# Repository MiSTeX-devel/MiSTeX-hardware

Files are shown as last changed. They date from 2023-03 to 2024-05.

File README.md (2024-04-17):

# MiSTeX-hardware

## Current
### MiSTeX baseboard for QMTech form factor FPGA boards
The QMTech-MiSTeX
baseboard is the current recommended platform. It can be used with Raspberry Pi Zero
form factor SBCs and QMTech form factor core boards.
Status: The `rev2` revision has been manufactured and tested working.

QMTech-MiSTeX Baseboard

### Using the Raspberry Pi Zero with MiSTeX, with a generic FPGA board
To connect the Raspberry Pi Zero to the FPGA board of your choice,
the pin mappings can be found in two places:
1. On the FPGA board side the pin mappings are defined in the board support file in MiSTeX-boards:
   FPGA pin mapping
2. On the Raspberry Pi Zero side, the pin mappings of the GPIO control signals are defined in Main_MiSTeX in fpga_io.cpp:
   RPi Zero pin mapping
   
   And the SPI bus is the SPI0 on the Raspberry Pi header:
   RPi SPI pins

## Obsolete
### MiSTeX Pmod
Status: Manufactured, waiting for arrival. Obsolete, Sipeed Lich





### MiSTeX cape for the Terasic DECA board
Status: Manufactured and tested working.





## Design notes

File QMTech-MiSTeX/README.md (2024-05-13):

# **MiSTeX Board**

### Connectors and main headers

- Headers for QMTech 128 pins FPGA format (2x 2x32)
- MiSTer SDRAM module header (Terasic 2x20)
- RPi header (Orange Pi 2W) (2x20)
- SNAC user port for gamepads / mt32pi (USB3)
- VGA video out (DB15)
- HDMI video out
- Analog audio out (delta sigma) (jack 3.5) 
- SPDID audio out (Toslink)
- Secondary uSD Card
- PMOD J11 header (GPIO / I2S / Delta-sigma)
- USB C for RP2040 programming
- USB C power supply

### Power Supply

It is recommended to use the USB power port since it uses a voltage filter. This port supply power to FPGA and Orange Pi as well.

The Jumper on the power port is for an external power switch mounted in a case for example. 

<u>J18 needs to be shorted with a jumper if no switch is placed</u>.



You can of course also power the board from the core board barrel jack.

### FPGA programming

Connect an USB-C from RP2040 port to the USB HUB you are using

Connect Dupont wires from FPGA JTAG to JTAG header on MiSTeX board

### Switches / Jumpers / small headers / Leds

J9 RC2040 Boot jumper. Short to reprogram RC2040 firmware

J10 SCART VGA pin 9 jumper. Short to use a VGA to SCART cable

J18 Power switch (or either place a jumper if no switch is added)

IO6 Jumper - By default shorted 2-3 for most gamepads. Some accessories require additional 3V3 power supply, in that case put jumper in position 1-2 next to +3V3 text.

SW1 Button User (RPi/Orange Pi)

SW2 Button OSD  (RPi/Orange Pi)

SW3 Button Reset  (RPi/Orange Pi)

SW4 Button Menu  (RPi/Orange Pi)

The side switches SW5, SW6 are currently unused and have been erroneously momentary in rev1, but should actually be latching which has been fixed in rev2

- SW5 (FPGA) will be used to switch the Pmod signals from I2S to general purpose use

- SW6 (RPi/Orange Pi)  is intended to switch the SNAC port from SNAC to mt32pi mode

The DIP switches are currently unused too  (RPi/Orange Pi).

User / HDD / Power Leds

DBG J7 Debug UART (RC2040)

SWD J12 Header (RC2040)

JTAG J6 Header   (RC2040)

ADC J14 Header (3 ADC + 1 GPIO)  (RC2040)

### SD image (placed at Orange Pi SD slot)

```sh
$ wget -c http://www.hans-baier.de/static/mistex-orangepizero2w.img.xz
$ md5sum mistex-orangepizero2w.img.xz
30ea6324ea5340d76d8ffbd25d986887  mistex-orangepizero2w.img.xz
```

The boot image needs the menu core at /media/fat/menu.bit
or menu.rbf for Altera boards
The sdcard image above is preconfigured for the Artix 100t QmTech with pre built cores
But A200T and K325T cores are included too
You only need to copy the right one to menu.bit

### RP2040 firmware

You need to bridge the boot jumper J9 and plug the RC2040 USB port into a PC to flash this firmware: https://github.com/MiSTeX-devel/pico-dirtyJtag/releases/tag/v0.0.1
The core FPGA board needs to be present there because it powers the 2040 except you power the 3.3v rails from another source.

Connect power supply either to FPGA barrel or USB-C power port.

Copy the uf2 file into the mass storage device that appears on PC. When the file disappears it means it is flashing the firmware. Wait a bit and disconnect USB-C and remove jumper.

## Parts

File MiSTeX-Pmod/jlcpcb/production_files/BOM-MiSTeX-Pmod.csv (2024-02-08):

Comment | Designator | Footprint | LCSC
100nF | C1 | C_0402_1005Metric | C1525
Connector_USB_C_Receptacle_USB2.0 | J5 | USB-C_SMD-TYPE-C-31-M-12 | C165948
LXES15AAA1-133 | D2,D3,D4,D5,D6,D7,D8 | D0402-BI | C191267
Schottky | D1 | D_SMA | C22452
100R | R3 | R_0402_1005Metric | C25076
22R | R1,R2 | R_0402_1005Metric | C25092
47R | R5,R6,R7,R8 | R_0402_1005Metric | C25118
TS-1187A-B-A-B | SW1 | SW-SMD_4P-L5.1-W5.1-P3.70-LS6.5-TL-2 | C318884
NASB0-S6701-TS50 | CN1,CN2 | CONN-SMD_67P-P0.50-V_NASB0-S6701-TS50 | C367024
USB_A | J2 | USB-A-SMD_GT-USB-2004-CWG1A | C5117890
JK-NSMD050-30V | F1 | F1206 | C720075
TestPoint | TP1 | TestPoint_Pad_D2.0mm
Pmod | J1 | Pmod 2x6
TestPoint | TP5 | TestPoint_Pad_D2.0mm
Conn_01x03_Male | J3 | PinHeader_1x03_P2.54mm_Vertical
Pmod | J4 | Pmod 2x6
MountingHole_Pad | H1 | MountingHole_2.2mm_M2_ISO7380_Pad_TopBottom
Sipeed Lichee | H2 | Sipeed Lichee

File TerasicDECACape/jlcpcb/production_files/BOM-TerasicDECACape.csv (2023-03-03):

Comment | Designator | Footprint | LCSC
USB_A | J2 | USB-A-SMD_USB-302S | C112455
100nF | C1 | C_0402_1005Metric | C1525
LXES15AAA1-133 | D10,D11,D12,D13,D14,D15,D16,D2,D3,D4,D5,D6,D7,D8,D9 | D0402-BI | C191267
Schottky | D1 | D_SMA | C22452
100R | R3 | R_0402_1005Metric | C25076
22R | R1,R2 | R_0402_1005Metric | C25092
47R | R5,R6,R7,R8,R9 | R_0402_1005Metric | C25118
10k | R4 | R_0402_1005Metric | C25744
TS-1187A-B-A-B | SW1,SW2 | SW-SMD_4P-L5.1-W5.1-P3.70-LS6.5-TL-2 | C318884
NASB0-S6701-TS50 | CN1,CN2 | CONN-SMD_67P-P0.50-V_NASB0-S6701-TS50 | C367024
JK-NSMD050-30V | F1 | F1206 | C720075
BeagleBone_Black_Header | P8 | Socket_BeagleBone_Black
BeagleBone_Black_Header | P9 | Socket_BeagleBone_Black
MiSTer SDRAM Module | J1 | PinHeader_2x20_P2.54mm_Vertical
Conn_01x03_Male | J3 | PinHeader_1x03_P2.54mm_Vertical
Conn_02x06_Odd_Even | J4 | PinSocket_2x06_P2.54mm_Vertical
MountingHole_Pad | H1 | MountingHole_2.2mm_M2_ISO7380_Pad_TopBottom
Sipeed Lichee | M1 | Sipeed Lichee
TestPoint | TP1 | TestPoint_Pad_D2.0mm
TestPoint | TP6 | TestPoint_Pad_D1.0mm
TestPoint | TP4 | TestPoint_Pad_D2.0mm
TestPoint | TP2 | TestPoint_Pad_D1.0mm
TestPoint | TP5 | TestPoint_Pad_D1.0mm
Conn_02x02_Odd_Even | J5 | PinHeader_2x02_P2.54mm_Vertical
TestPoint | TP3 | TestPoint_Pad_D1.0mm

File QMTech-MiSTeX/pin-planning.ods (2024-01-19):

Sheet: Pinstats
Total Pins |  | 108 | Remaining | 22
HDMI
 | Video | 24
 | Sync | 4
 | Audio | 1
 | I2C | 2
 | INT | 1
SDRAM |  | 36
HPS | SPI | 5
 | GPIO | 4
 | UART | 2
USER IO |  | 7

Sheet: Pinout
A100T | K325T
R55S
R56S
R50S | R52S
R49S | R51S
R46
R45
R38 | R36
R37 | R35
R31S
R32S
R24
R23
R22
R21
R20S | R18
R19S | R17
 | R14
 | R13
L17 | L15
L18 | L16
L35S | L33
L36S | L34
 | L25S
 | L26S
 | L29S
L41 | L30S
L42 | L57S
L47 | L58S
L48 | L53S
 | L54S

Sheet: Diffpairs
 |  |  | 100R
 | mm | mil | mil | mm
Defaultwidth | 0.25 | 9.84251968503937 | 6.05 | 0.15367
Default gap | 0.127 | 5 | 5 | 0.127
 |  |  | 8.08 | 0.205232
 |  |  | 8 | 0.2032
 |  |  |  | 0
 |  |  |  | 0

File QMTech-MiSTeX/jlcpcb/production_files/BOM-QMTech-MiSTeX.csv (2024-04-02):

Comment | Designator | Footprint | LCSC
10uH | L1,L2,L3,L4,L5 | L0805 | C1046
UWX1C101MCL1GB | C47 | CAP-SMD_BD6.3-L6.6-W6.6-FD | C111600
1k | R11,R31,R36,R37,R53,R54,R55,R56,R59,R60,R61,R63,R65,R70,R9 | R_0402_1005Metric | C11702
W25Q128JVS | U1 | SOIC-8_5.23x5.23mm_P1.27mm | C131025
100n | C43,C52 | C_0603_1608Metric | C14663
100uF | C41,C42,C46 | C1206 | C15008
10nF | C37,C38,C39,C40 | C_0402_1005Metric | C15195
100nF | C1,C11,C12,C13,C14,C15,C16,C23,C24,C25,C26,C27,C28,C29,C30,C31,C32,C33,C34,C35,C4,C44,C5,C55,C6,C9 | C_0402_1005Metric | C1525
30pF | C2,C3 | C_0402_1005Metric | C1570
1u | C10,C17,C7 | C_0603_1608Metric | C15849
10u | C53 | C_0805_2012Metric | C15850
USB_C_Receptacle_USB2.0 | J13,J3 | USB_C_Receptacle_XKB_U262-16XN-4BVC11 | C165948
10n | C51 | C_0805_2012Metric | C1710
0R | R14,R17,R18,R19,R20 | R_0402_1005Metric | C17168
0R | R1,R3 | R_0805_2012Metric | C17477
10u | C18,C19,C20,C21,C22,C36,C45,C54,C8 | C_0603_1608Metric | C19702
1k | RN1,RN10,RN11,RN12,RN13,RN14,RN15,RN2,RN3,RN4,RN5,RN6,RN7,RN8,RN9 | RES-ARRAY-SMD_0603-8P-L3.2-W1.6-BL | C20197
RP2040 | U2 | LQFN-56_L7.0-W7.0-P0.4-EP | C2040
0R | R52,R74 | R_0603_1608Metric | C21189
16k | R28,R29,R30 | R_0603_1608Metric | C22818
blue | D7 | LED_0805_2012Metric | C2293
1M | R22,R25,R35,R39,R6 | R_0603_1608Metric | C22935
5k1 | R7,R71,R72,R8 | R_0603_1608Metric | C23186
560R | R32,R33,R34,R47,R48,R49,R50,R73 | R_0603_1608Metric | C23204
100R | R26,R27,R40,R41,R42,R43,R44,R45,R46 | R_0402_1005Metric | C25076
51R | R5 | R_0402_1005Metric | C25125
27R | R12,R13 | R_0603_1608Metric | C25190
10k | R21 | R_0402_1005Metric | C25744
4.7k | R38,R57,R58,R62,R64,R66,R67,R68,R69 | R_0402_1005Metric | C25900
ZGY133/T10(PLT) | U5 | COMM-TH_ZGY133-T10-PLT | C277782
PJ-325C5-BL | CN1 | TH_PJ-325C5-B | C2884946
TPD4E05U06DQAR_C2972498 | D1,D10,D12,D13,D14,D2,D3,D4,D5,D9 | DFN2510-10_L2.5-W1.0-P0.50-BL | C2972498
U-A-39WD-W-1 | USB1 | USB-A-SMD_U-A-39WD-W-1 | C3020886
KH-HDR15P-F3.08 | VGA1 | DSUB-TH_KH-HDR15P-F3.08-VGA | C3038673
6A | FB1 | L_1206_3216Metric | C304333
TS-1187A-B-A-B | SW1,SW2,SW3,SW4 | SW-SMD_4P-L5.1-W5.1-P3.70-LS6.5-TL-2 | C318884
white | D6 | LED_0805_2012Metric | C34499
DSHP04TSGER | SW7 | SW-SMD_8P-L6.7-W5.4-P1.27-LS8.4 | C40736
ADV7513BSWZ | U4 | LQFP-64_L10.0-W10.0-P0.50-LS12.0-BL-EP5.3 | C408901
2k | R16,R23,R24 | R_0402_1005Metric | C4109
887R | R15 | R0402 | C474137
100nF | C48,C49,C50 | C_0805_2012Metric | C49678
TPS76318 | U3 | SOT-23-5 | C7099
D_LED_0603_Yellow | D15 | LED_0603_1608Metric | C72038
HDMI-001S | HDMI1 | HDMI-SMD_HDMI-001S | C720616
TF-CARD H1.8 | TF1 | TF-SMD_TF-CARD-H1.8 | C7529389
XKB5858-W-F-75 | SW5,SW6 | SW-SMD_XKB5858-W-F-75 | C780036
P6SMB6.8CA-C78395 | D11 | SMB_L4.6-W3.6-LS5.3-BI | C78395
red | D8 | LED_0805_2012Metric | C84256
U.FL-R-SMT-1(80) | CN2,CN3,CN4,CN5,CN6,CN7,CN8 | RF-SMD_FRF05002-JSS103M | C88374
X322512MSB4SI | X1 | OSC-SMD_4P-L3.2-W2.5-BL | C9002

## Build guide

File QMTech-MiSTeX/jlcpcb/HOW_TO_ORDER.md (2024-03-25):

# How to order
These are the settings I used. You probably
can use cheaper options where I mentioned it,
but I have not tried those, so do that at your own risk.

1. Go to https://cart.jlcpcb.com/quote
2. Click `Add Gerber File`
3. Choose `production_files/GERBER-QMTech-MiSTeX.zip`
4. Material type: FR4-TG155 (optional, costs marginally more, less warping)
5. Surface finish: ENIG (optional, lead free HASL also might work)
6. Impedance control: Yes, JLC04161H-7628, press `Confirm`
7. Leave the rest at default (optionally use `Confirm production file`), activate the Assembly switch
8. Confirm parts placement: Yes (important, the import of those is not perfect and has to be corrected by an employee,
                                 so you need to check if the placements are good)
9. PCBA Qty: I recommend 5, because it only costs about 20% more and does not waste PCBs, but use 2 at your own discretion.
10. Make sure `Assemble top side`  is chosen
11. Click `Confirm`
12. A PCB viewer will come up, press 'Next'
13. Select `production_files/BOM-QMTech-MiSTeX.csv`  as BOM file and `production_files/CPL-QMTech-MiSTeX.csv` as CPL file
14. Press `Process BOM & CPL`
15. A list of parts should come up. Make sure they are all available and press `Next`
16. A window with the component placements comes up. Note that some connectors (USB-C, VGA and TOSLINK)
    can be out of place. Just leave them. A JLCPCB engineer will fix those, and then ask you for review
    after the order has been submitted (Confirm parts placement).
17. Press 'Save to Cart'
18. You can then Check out our cart and order the PCBs

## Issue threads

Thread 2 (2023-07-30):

Addressing MiSTer shortcomings with MiSTeX in the future?

jan-kleks, 2023-07-30:
Hello,

This is a great project, and I am quite sure that I am not the only person closely watching it. MiSTer is awesome, but it has some shortcomings:

- you have to take additional actions to make sure your game is saved: https://mister-devel.github.io/MkDocs_MiSTer/basics/saves/ This is the case even with Autosave turned on: https://www.youtube.com/watch?v=V0s-lkA9MD8 -- the devices from Analogue do not have this problem.

- only one SNAC port

- USB input could be more in sync with the cores. See: https://www.atari-forum.com/viewtopic.php?f=117&t=38741

- maybe the framework could be adapted to make it easier to add save states to cores. At least those flashcart-like save states, see the discussion from Discord about them:

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

- it would be nice if a MiSTeX FPGA board could have more than one "retro use". Have you seen this video about creating a Game-Genie for Atari 2600 with a DE0-Nano FPGA board? -- https://www.youtube.com/watch?v=lXTxKD8-ghg

It might be worth looking into turning a MiSTeX board in a similar way into a "multi-flashcart" for developers. With wide-range support of mappers/expansion chips in MiSTer FPGA, I guess it could have been used together with various gaming retro hardware.

One could utilize it, for instance, for homebrew development (see how this scene is evolving! -- https://www.youtube.com/watch?v=1AGMEZvU14g) or creating test ROMs to compare FPGA implementations with original devices without buying "tons" of flashcarts.

Though obviously not as portable and nice-looking as standard flashcarts -- for development it should be just fine.

Using MiSTeX as a video scaler for original consoles/computers could be another interesting idea…

Keep up the great work!

hansfbaier, 2024-04-17:
Yes, you could use it as a game genie.
The SDRAM port uses the same layout as the Altera DE0 boards, and you
can also plugin in standard MiSTer SDRAM modules.
Of course, you can plug in anything else there.
You just have to be careful what core you load.
The baseboard is actually quite general purpose,
you can also use it as a dev board for educational purposes.

hansfbaier, 2024-04-17:
Why shouldn't you be able to use it for homebrew development?
What features would that need?

jan-kleks, 2024-04-17:
> Why shouldn't you be able to use it for homebrew development? What features would that need?

I mean, it would have been nice to be able to use it like a universal flashcart with a set of additional exchangeable hardware "cartridge-like plugs" that you would put into a given console. In general, it would have been cool if MiSTeX was even more than a universal console/computer.

hansfbaier, 2024-04-18:
Of course you can use it like that with the SDRAM port and custom gateware.
No problems with that, but you really would not need the baseboard for that.
You could also use the core board for that.
In any case you would need a suitable adapter for the cartriges.

tomaszb-dev, 2024-05-21:
Hello,
Will the board be appropriate for the project.
QMTECH Xilinx FPGA Kintex7 Kintex-7 XC7K325T DDR3

hansfbaier, 2024-05-23:
@tomaszb-dev You mean this one?
https://de.aliexpress.com/item/1005003668804223.html
You can use it even now. I recently built all working core ports for it also.
I just don't recommend it for development work because you need a paid license ($3k).
Also currently it offers no material advantage over a 100T and a 200T because there are no cores that would use its strength.

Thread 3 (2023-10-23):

rpi-zero wiring diagram

siffland, 2023-10-23:
Is there an updated diagram or pinout how you are attaching the rpi-zero to the FPGA boards, preferably the qmtech boards.

Thanks,
Sean

hansfbaier, 2023-10-24:
Hi, the Pin assignments can be found in the
python build files in MiSTeX-boards:
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
You need to wire up those to the SPI0 and the four GPIO lines I configured in the MainMiSTeX binary.
I didn't have the time to do it myself, my paid work is rather demanding at the moment.
Here are the Pin assignments:
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

hansfbaier, 2023-10-25:
https://pinout.xyz/pinout/pin32_gpio12/

hansfbaier, 2023-11-07:
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

hansfbaier, 2023-11-07:
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

hansfbaier, 2023-11-07:
OK, added this information to the README, closing this issue:
https://github.com/MiSTeX-devel/MiSTeX-hardware/blob/main/README.md

Closed 2023-11-07.

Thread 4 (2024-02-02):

QMTech hardware

DFL1973, 2024-02-02:
Hello, I just saw the PCB for QMtech that you added a few days ago. Is it working already or is it just an untested concept?
Thanks for sharing, you are doing a great job!

hansfbaier, 2024-02-02:
Hi, I will find out tomorrow or on Monday, when the boards arrive at my home.

hansfbaier, 2024-04-17:
Hi it is working!
You can order rev2, and see the picture in the README, I just updated it.

Closed 2024-04-17.

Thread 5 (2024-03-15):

MiSTeX coming along

magwed, 2024-03-15:
Nice to see that this is still in development. Where is the general channel for chatting/sharing info about MiSTeX? I can't see any discussion forum here, there is no facebook group and I can't find anything in Discord. Are there anything hidden that I can get myself invited to or is this a closed project right now? I'm really interested in seeing where this can lead, what tool chains that are used, how the hardware currently are working, which hardware is used, what's next? Thanks!

no-shad, 2024-03-15:
On the patreon there was an invite to a group posted but I found it to be expired when I tried to join

hansfbaier, 2024-03-16:
@magwe @no-shad I updated the Link on Patreon: Here is the invite:
https://t.me/+kuN3TVEjBSAxMDg0

Closed 2024-03-16.

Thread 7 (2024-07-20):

MisteX hardware questions

ole00, 2024-07-20:
HI,
MisteX looks like an interesting project. Is there an update what are the current hardware components for MisteX base board? I saw that in the past you were using Allwinner D1, there are mentions of Orange Pi 2W and Raspberry Pi Zero. There also seem to be a RPi 2040 IC on the Mistex Board? You don't seem to have pictures how all these boards connect together. Also there seem to be some hardware on the Mistex Base board that looks to be optional (is it?) like HDMI, uSD card etc.

I think for the clarity of the project it would be good to document:

**1) what is the bare minimum HW components on the MisteX baseboard:**
- Is Rpi 2040 required ? If so, what purpose does it serve?
- Is uSD card required? I think MiSTer does not seem to use it much these days.
- Is HDMI required? Is the VGA functional without HDMI?
- Is the IC next to HDMI connector related to HDMI signal generation ? Can it be omitted if HDMI is not used?
- Is USB-C required for Power? If not, what voltage and amp rating Power supply can be used for powering MisteX?
- What are these SMA connectors for and do they need to be populated? Are they all required?
- What is the USB-A connector for ? Is it for SNAC? Is SNAC required?

The purpose of this doc/QA would be to find the smallest (and simplest to build) configuration of a functional
MisteX board. For example I don't need HDMI, I'd be happy to use external power supply (Without USB-C) and I don't
need SNAC if the Rpi Zero can be used for input.

**2) Which SBC is required** (Rpi Zero, Orange Pi ?), which one is supported by the Buildroot image? What is your favourite one that will be (likely) supported going forward?

**3) Which FPGA modules are supported** and could you provide a link where to buy them? If there are multiple, which one  is more likely be supported in the future?

Thanks.
Apology if these questions are already answered.

EDIT: I can see you have a  JLCPCB directory for production and assembly of the base board. That's a good option however it adds costs and from my experience the ICs may not always be available at LCSC, so the production my not be fully done if there is a shortage of particular chip.  I would prefer to build MisteX base board on my own - and to make it simple I'd like not to use the small pitch IC and passives (0402 are not very friendly to solder at home) - I guess that would mean redesign of the board - hence my questions above, which are related to very minimal yet functional MisteX base board.

EDIT2: Checking the Aliexpress site for MisteX compatible QMTECH FPGA module,  I found this board:
QMTECH Intel Altera CycloneV Cyclone V SoC FPGA 5CSEMA6U23 Development Board
which may be compatible with MiSTer on hardware level (and seems to have on board SDRAM, reducing the overall costs of the MiSTer system). Therefore, unless a new FPGA core needs  more FPGA resources than MiSTer can support, then building MisteX probably does not make much sense (it is still a good hobby project and and and electronic skill exercise though).

hansfbaier, 2024-07-21:
Hi, sorry for the late replay, just came back from vacation.
Here the answers:
1)
* The onboard rp2040 works as a JTAG adapter using pico-dirtyJtag, used to program the FPGA
* A uSD card is only required for the Orange Pi Zero 2W. Currently no working ported cores use the SDCARD slot on the baseboard. But the minimig may in the future.
* Yes VGA works without HDMI. It uses the same signal path than HDMI of MiSTer (not the MiSTer VGA signal path)
* Yes it is the HDMI chip used on the DE10 nano, and it may be left out if no HDMI is needed
* The backside USB-C connector is for power only and a 5W power supply may be enough
* The uFL connectors are for oscilloscope connection (debugging the board) with an integrated 1k-resistor probe. They do not need to be populated in production
* Yes it is for SNAC and it is not required if you don't use SNAC
2) We currently use the Orange Pi Zero 2W. Great price and performance. (RPi zero version one also works but is slow).
3) The supported boards are currently:
https://de.aliexpress.com/item/4000170003461.html
https://de.aliexpress.com/item/1005002960622091.html
https://de.aliexpress.com/item/1005003668804223.html
But the A100T variant is the main target at the moment, since it is enough for all ported cores, and probably will be for all other cores at the moment.
If QMTech still don't ship to germany, you can also order via taobao.com
using the item link https://world.taobao.com/item/694209022837.htm
for the A100T board.
This is the TaoBao store of QMTech: https://world.taobao.com/dianpu/61835962.htm

Yes the QMTech CycloneV board may be MiSTer compatible and won't need MiSTeX.
Not sure if it is pin compatible, but at worst you will need to recompile the game cores with different pin assignments.

hansfbaier, 2024-07-23:
By the way, if you want a ready made board, you can ask in our community channel.
There are still members with spare boards.
https://t.me/+kuN3TVEjBSAxMDg0

ole00, 2024-07-23:
Thank you for the answers. I appreciate your time answering my questions.  I like your effort of porting MiSTer to other HW platforms. I would prefer an FPGA with open source toolchain, something like this (the i9 option):
https://de.aliexpress.com/item/1005002997672924.html?spm=a2g0o.productlist.main.3.540aLRSTLRSTpn
I understand, there is not nearly as much as LUTs on ECP5 (only 44k) compared to Xilinx boards you use, so these
may not be a good option for a MiSTer port. OTOH they are slightly cheaper than the QMTECH FPGA boards.

Ready made MisteX board: I think I'll try something a bit different. The idea is to use real retro CPUs and exchangeable audio chips (via pluggable cards with real AY-3 or YM2204) on a base board. Then to have a smaller grade reprogrammable CPLDs and a FPGA to provide a glue logic and a video circuitry for the game/machine to operate correctly with the original software.  I'd probably start with a dual Z80 configuration - these were quite popular in 80s and there are some nice machines.

hansfbaier, 2024-07-24:
There is an open source toolchain
https://github.com/openXC7
And yes the Lattice part is too small.
And the system verilog and VHDL capabilities of the open source toolchains are currently the main limitation for MiSTer cores.

hansfbaier, 2024-07-24:
That is a yosys problem

ole00, 2024-07-24:
Thanks for the link to openXC7 - I was not ware such a tool exists. Did you attempt to compile MisteX cores by openXC7? If so, did it work?

> That is a yosys problem

I'm not sure I understand the context. Did you mean that yosys can be used to compile code for Altera's FPGAs, but currently unable to produce/fit Cyclon V binaries?

hansfbaier, 2024-07-24:
Yosys is the synthesis frontend for any architecture. Its system verilog and VHDL psrsers have limitations.

ole00, 2024-07-25:
I see, so that means MiSTer and MiSTEX FPGA cores can't be 'compiled' by Yosys (at this time) because of some limitations. I guess the only remedy would be to improve Yosys parser to support the limiting /missing functionality. Is there a list of what is missing / not supported by the parser, specifically for MiSTer/MisteX?

hansfbaier, 2024-07-25:
not really I think apart from the yosys issue tracker. I would just try it out, where it falls short

Closed 2024-07-21.

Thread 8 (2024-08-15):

BOM

tomaszb-dev, 2024-08-15:
Hello,
So i acquired the xillinx fpga board and ordered MisteX pcb. Maybe it's me but I cannot find any BOM for the parts.

hansfbaier, 2024-08-15:
Hello,
the complete production files including the BOM are here:
https://github.com/MiSTeX-devel/MiSTeX-hardware/tree/main/QMTech-MiSTeX/jlcpcb/production_files

They are actually complete for JLCPCB assembly, so you can have the complete board made there for comparatively
little money.

Also in the Telegram community chat there are several people who still have spare boards to sell.
I am closing this issue, please comment below if you have further questions.

hansfbaier, 2024-08-15:
No it is a 4 layer board

hansfbaier, 2024-08-15:
Please ask in the community chat,
several members have an assembled board to sell
https://t.me/+kuN3TVEjBSAxMDg0

tomaszb-dev, 2024-08-15:
By the way will you open a channel on discord

tomaszb-dev, 2024-08-15:
That will be much cheaper (40 Euro or so). Maybe I will do so. However I already ordered 5 PCBs. I will have to solder them. It will be a lot of resistors and caps :D

Closed 2024-08-15.

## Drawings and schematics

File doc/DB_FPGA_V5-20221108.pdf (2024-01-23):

RP2040

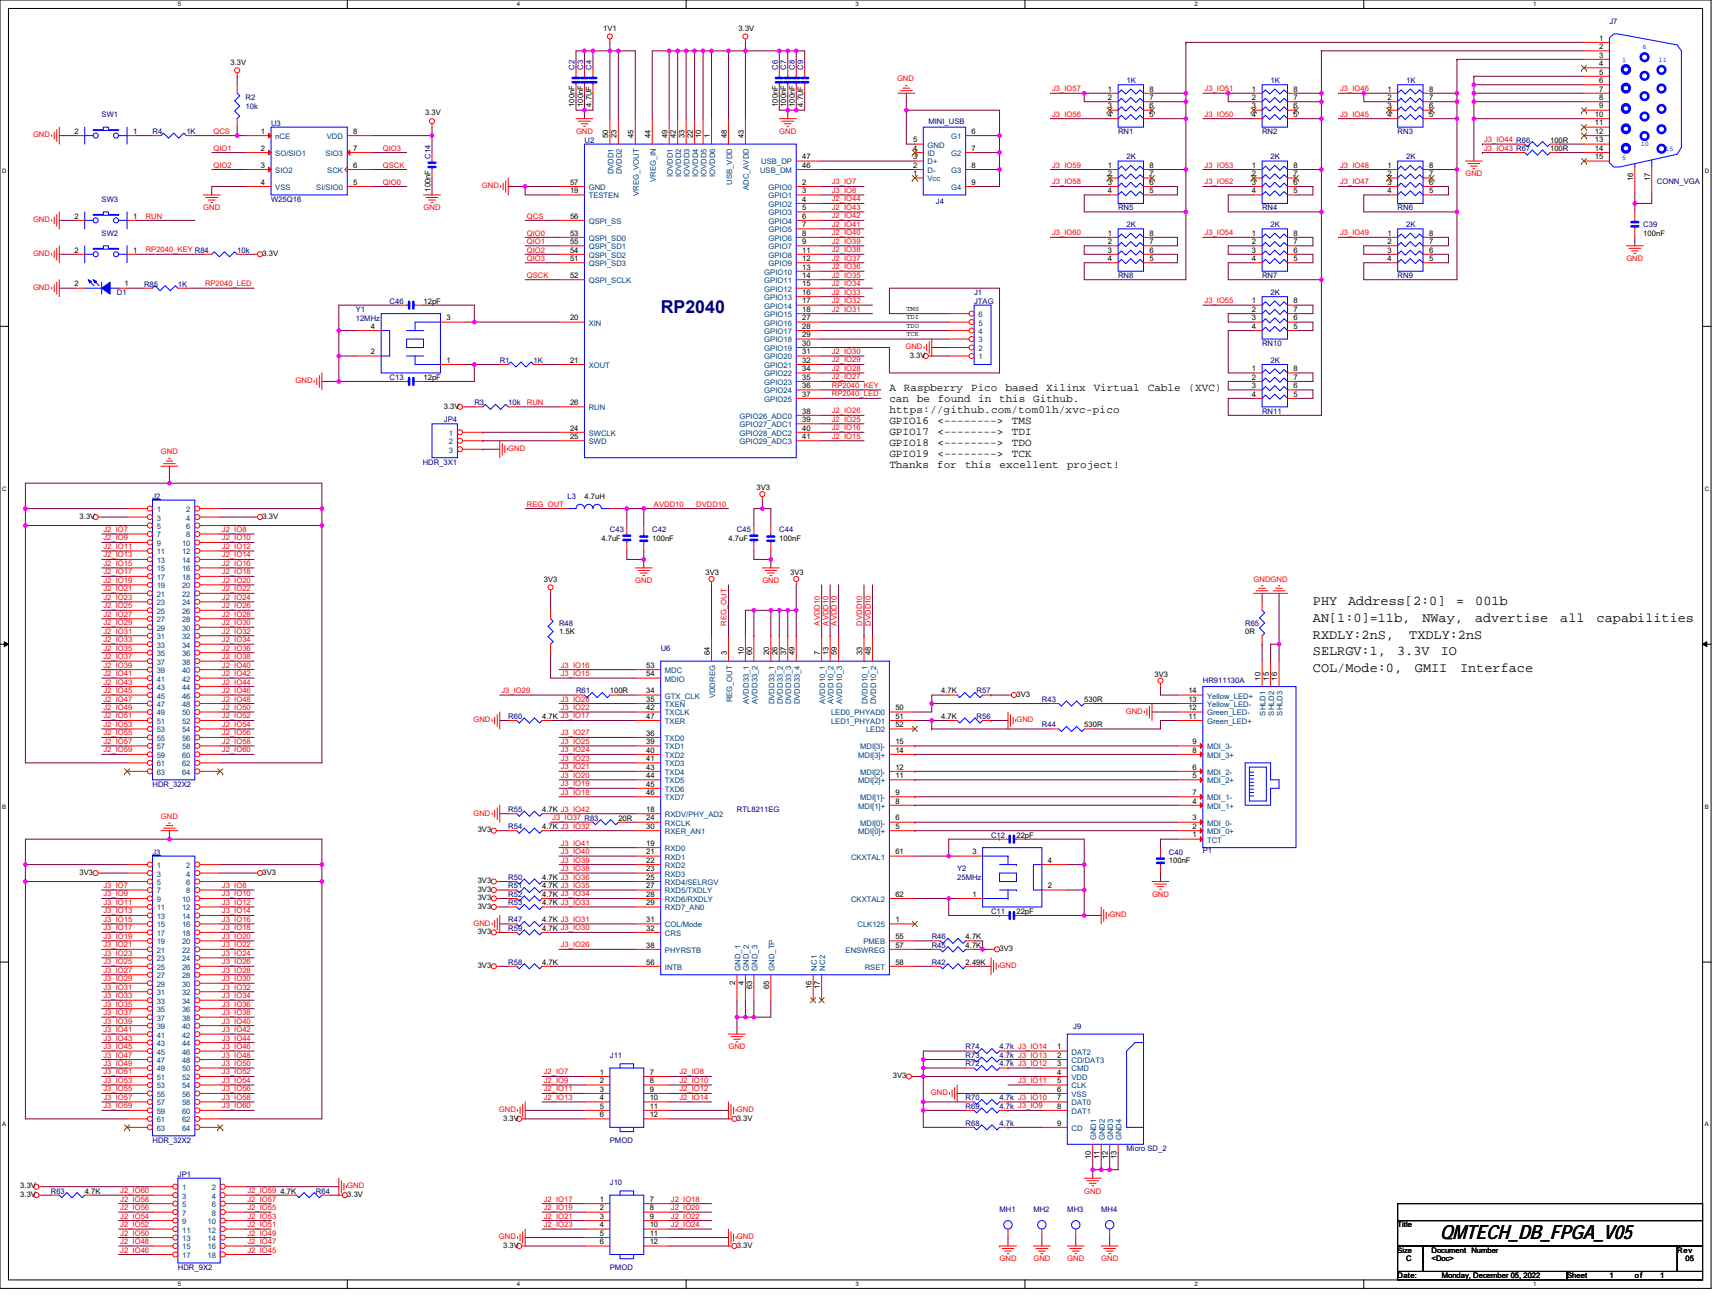
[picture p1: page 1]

A Raspberry Pico based Xilinx Virtual Cable (XVC)
can be found in this Github.
https://github.com/tom01h/xvc-pico
GPIO16 <--------> TMS
GPIO17 <--------> TDI
GPIO18 <--------> TDO
GPIO19 <--------> TCK
Thanks for this excellent project!

GND
PHY Address[2:0] = 001b
AN[1:0]=11b, NWay, advertise all capabilities
RXDLY:2nS, TXDLY:2nS
SELRGV:1, 3.3V IO
COL/Mode:0, GMII Interface

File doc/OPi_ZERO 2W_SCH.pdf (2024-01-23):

D | D

# 1.Note that the voltage of SOC GPIO must matches the

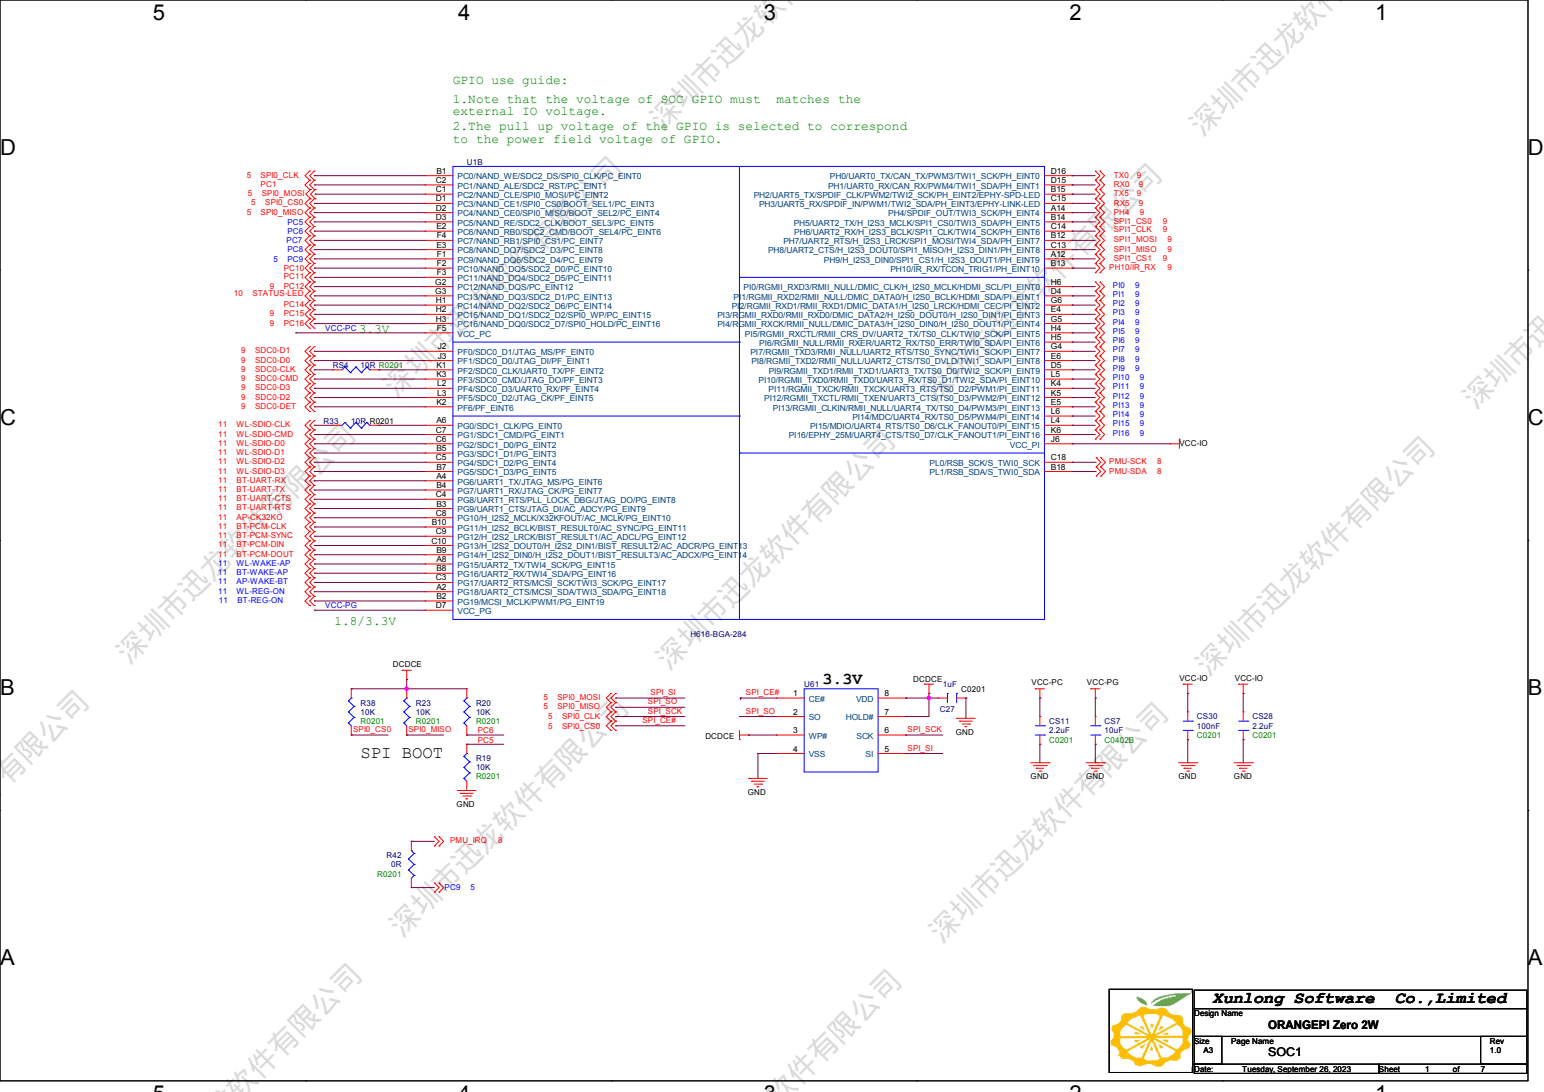
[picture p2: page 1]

深圳市迅龙软件有限公司 深圳市迅龙软件有限公司 深圳市迅龙软件有限公司 深圳市迅龙软件有限公司 深圳市迅龙软件有限公司 深圳市迅龙软件有限公司 深圳市迅龙软件有限公司 深圳市迅龙软件有限公司 深圳市迅龙软件有限公司 深圳市迅龙软件有限公司 深圳市迅龙软件有限公司 深圳市迅龙软件有限公司 深圳市迅龙软件有限公司 深圳市迅龙软件有限公司 深圳市迅龙软件有限公司

GPIO use guide:
external IO voltage.
2.The pull up voltage of the GPIO is selected to correspond
to the power field voltage of GPIO.

Xunlong Software Co.,Limited

D | D

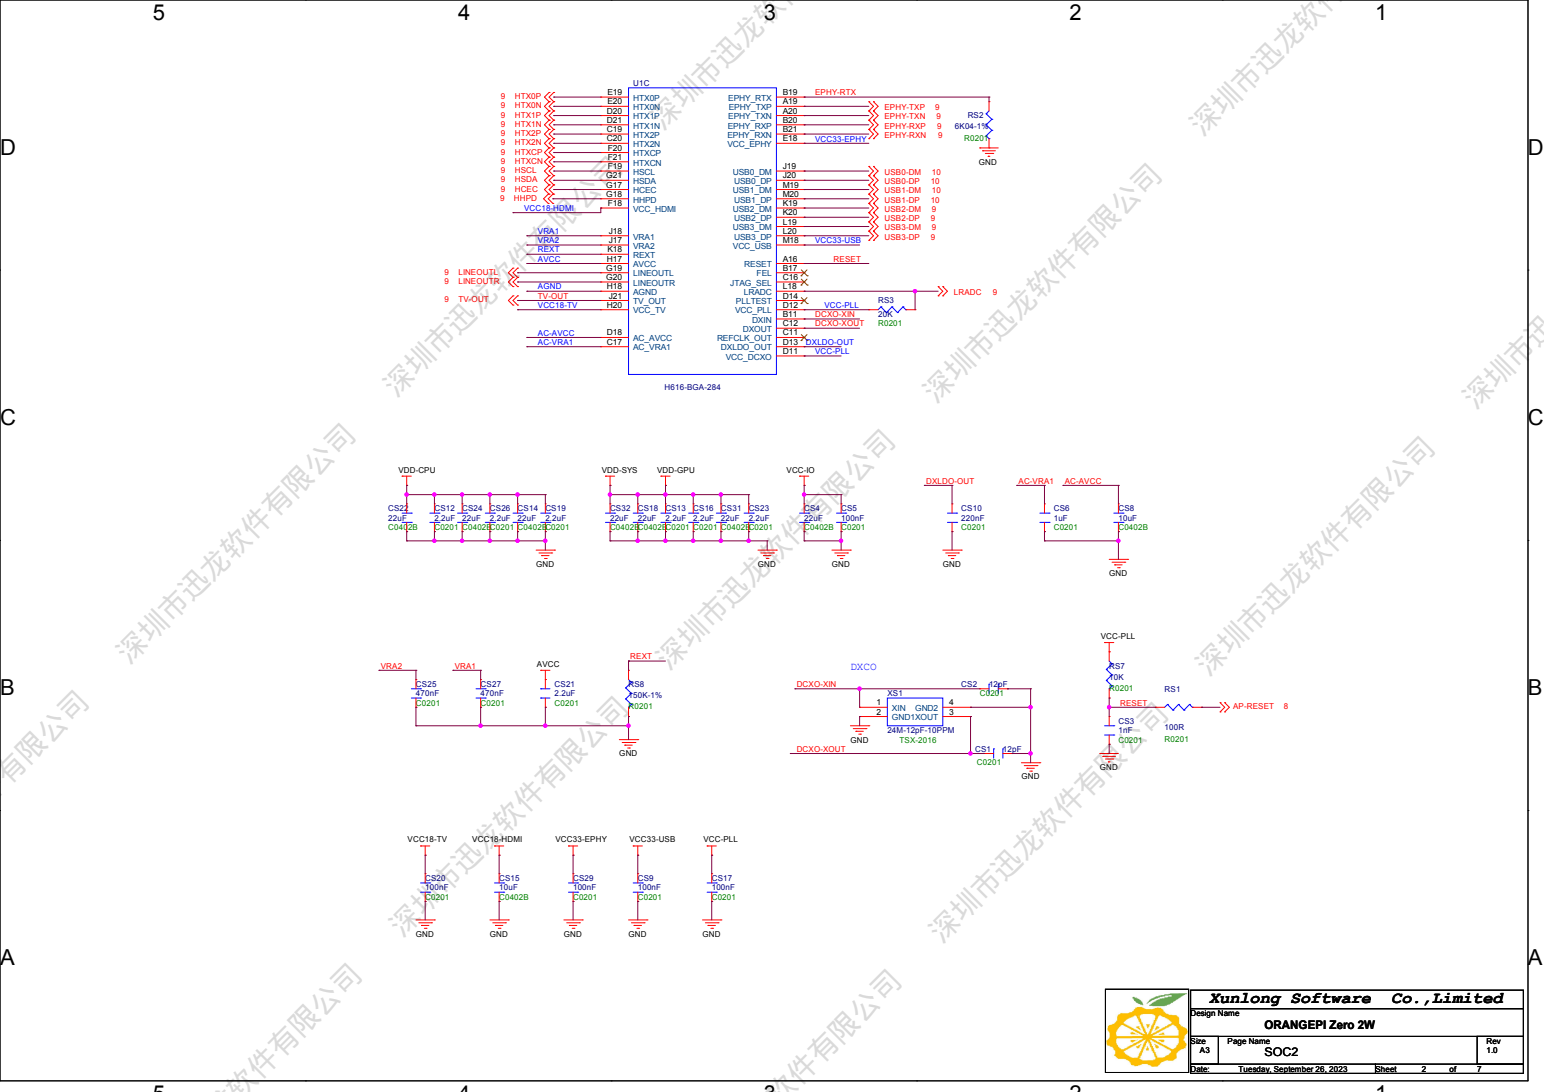
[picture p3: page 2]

深圳市迅龙软件有限公司 深圳市迅龙软件有限公司 深圳市迅龙软件有限公司 深圳市迅龙软件有限公司 深圳市迅龙软件有限公司 深圳市迅龙软件有限公司 深圳市迅龙软件有限公司 深圳市迅龙软件有限公司 深圳市迅龙软件有限公司 深圳市迅龙软件有限公司 深圳市迅龙软件有限公司 深圳市迅龙软件有限公司 深圳市迅龙软件有限公司 深圳市迅龙软件有限公司 深圳市迅龙软件有限公司

Xunlong Software Co.,Limited

D | D

# LPDDR4

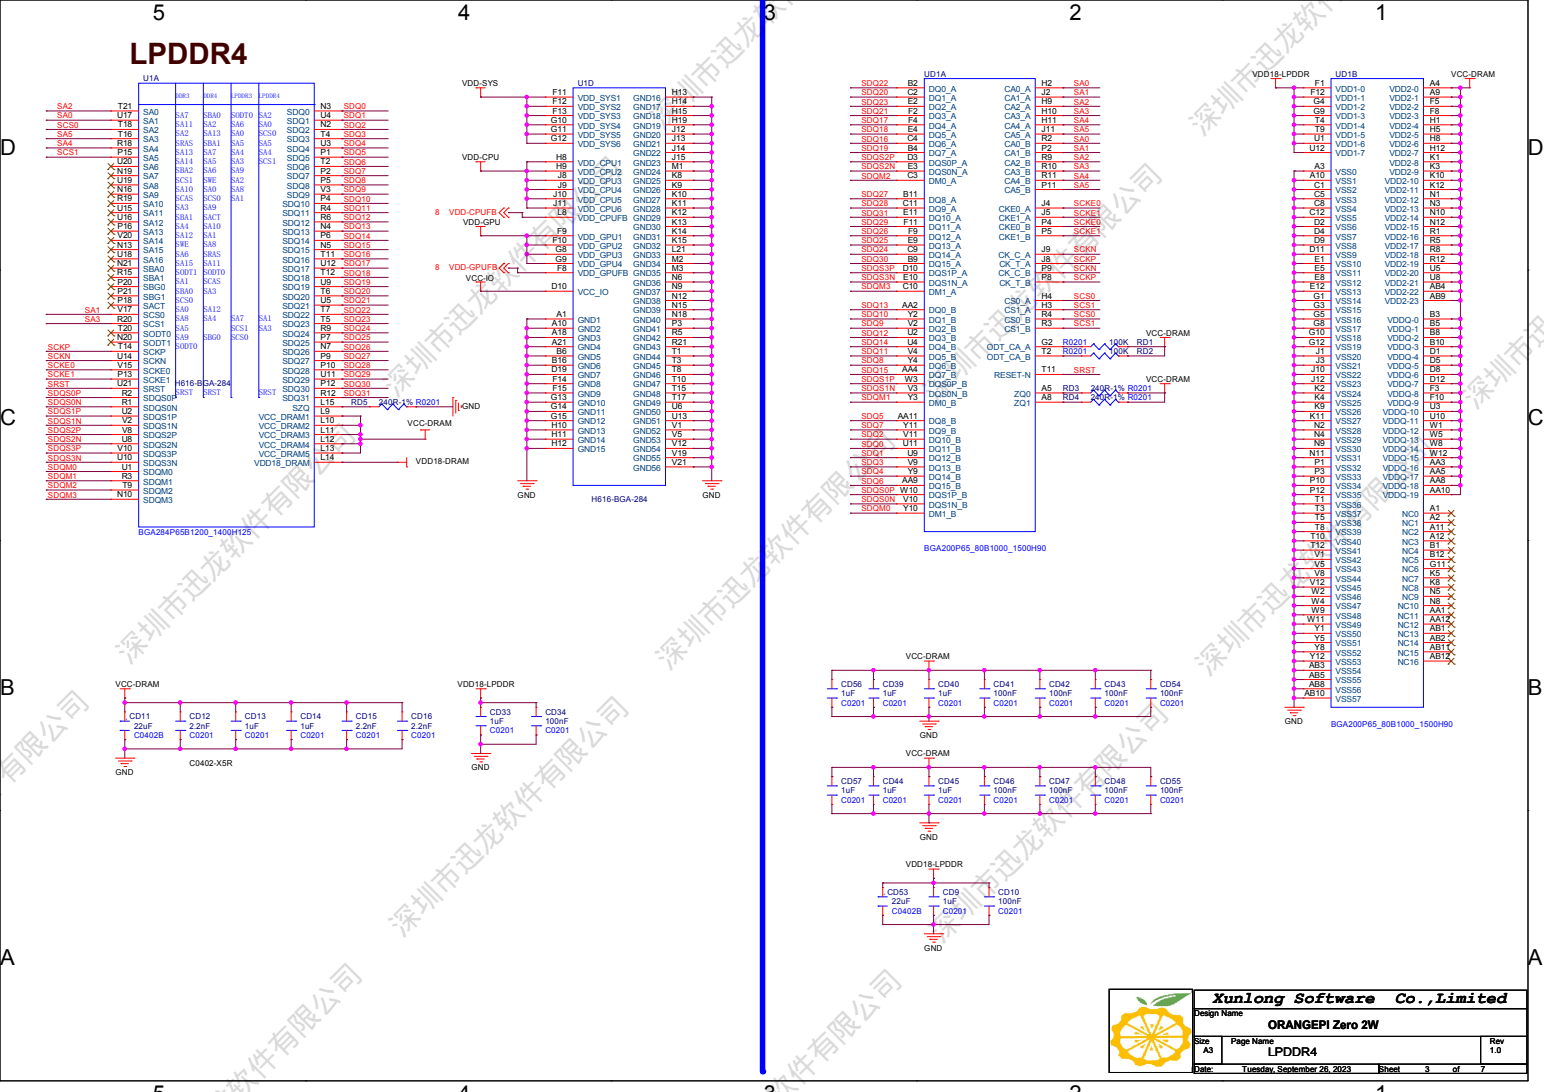
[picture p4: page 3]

深圳市迅龙软件有限公司 深圳市迅龙软件有限公司 深圳市迅龙软件有限公司 深圳市迅龙软件有限公司 深圳市迅龙软件有限公司 深圳市迅龙软件有限公司 深圳市迅龙软件有限公司 深圳市迅龙软件有限公司 深圳市迅龙软件有限公司 深圳市迅龙软件有限公司 深圳市迅龙软件有限公司 深圳市迅龙软件有限公司 深圳市迅龙软件有限公司 深圳市迅龙软件有限公司 深圳市迅龙软件有限公司

Xunlong Software Co.,Limited

### 1.0uH@2ADCR<0.1R

# AXP313A

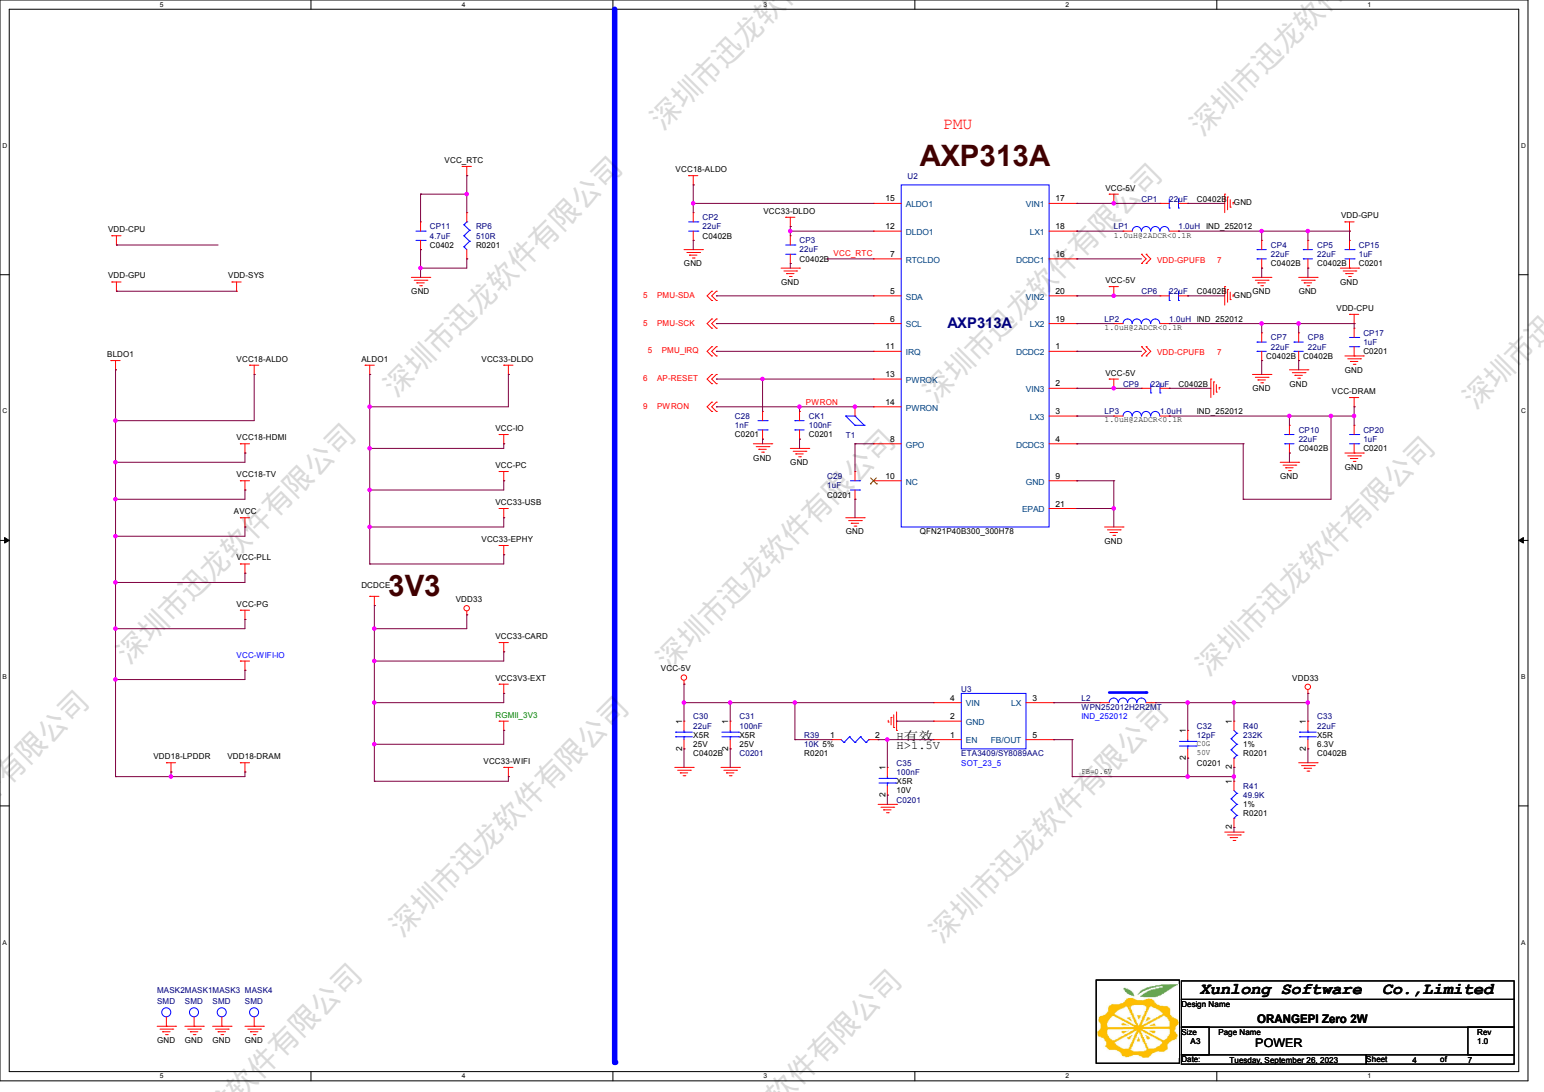
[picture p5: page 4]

深圳市迅龙软件有限公司 深圳市迅龙软件有限公司 深圳市迅龙软件有限公司 深圳市迅龙软件有限公司 深圳市迅龙软件有限公司 深圳市迅龙软件有限公司 深圳市迅龙软件有限公司 深圳市迅龙软件有限公司 深圳市迅龙软件有限公司 深圳市迅龙软件有限公司 深圳市迅龙软件有限公司 深圳市迅龙软件有限公司 深圳市迅龙软件有限公司 深圳市迅龙软件有限公司 深圳市迅龙软件有限公司

Xunlong Software Co.,Limited

D | D

# T CARD

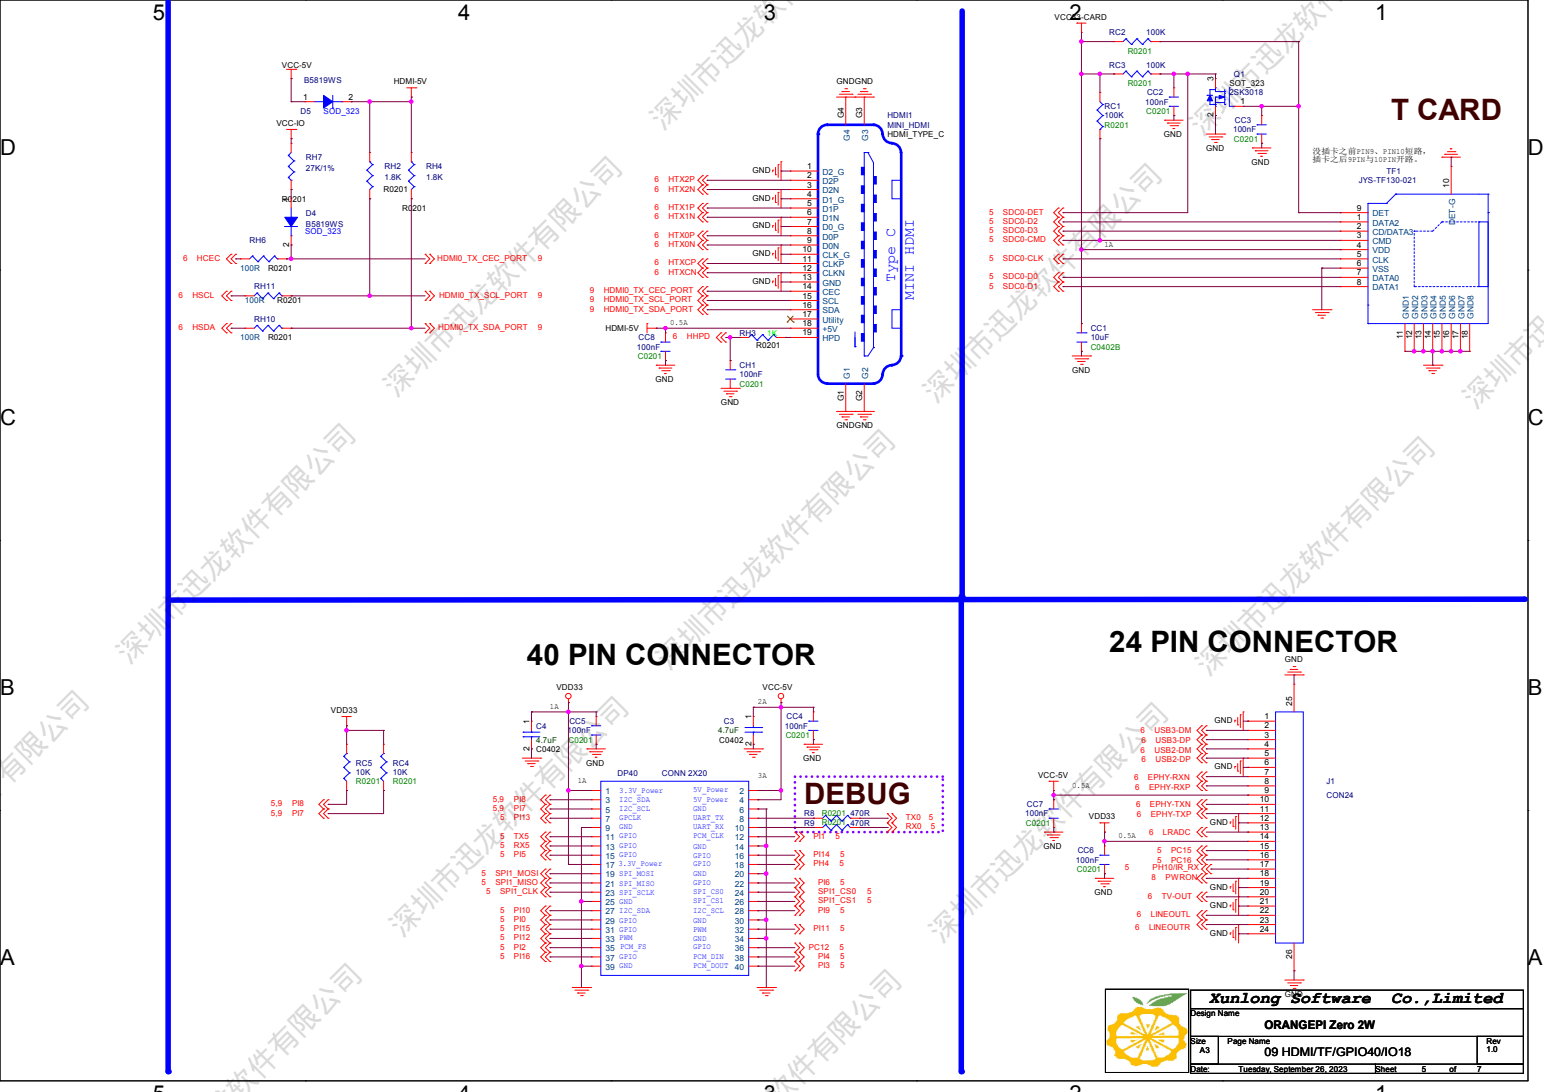
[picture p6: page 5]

深圳市迅龙软件有限公司 深圳市迅龙软件有限公司 深圳市迅龙软件有限公司 深圳市迅龙软件有限公司 深圳市迅龙软件有限公司 深圳市迅龙软件有限公司 深圳市迅龙软件有限公司 深圳市迅龙软件有限公司 深圳市迅龙软件有限公司 深圳市迅龙软件有限公司 深圳市迅龙软件有限公司 深圳市迅龙软件有限公司 深圳市迅龙软件有限公司 深圳市迅龙软件有限公司 深圳市迅龙软件有限公司

24 PIN CONNECTOR 40 PIN CONNECTOR

Xunlong Software Co.,Limited

D

## GND

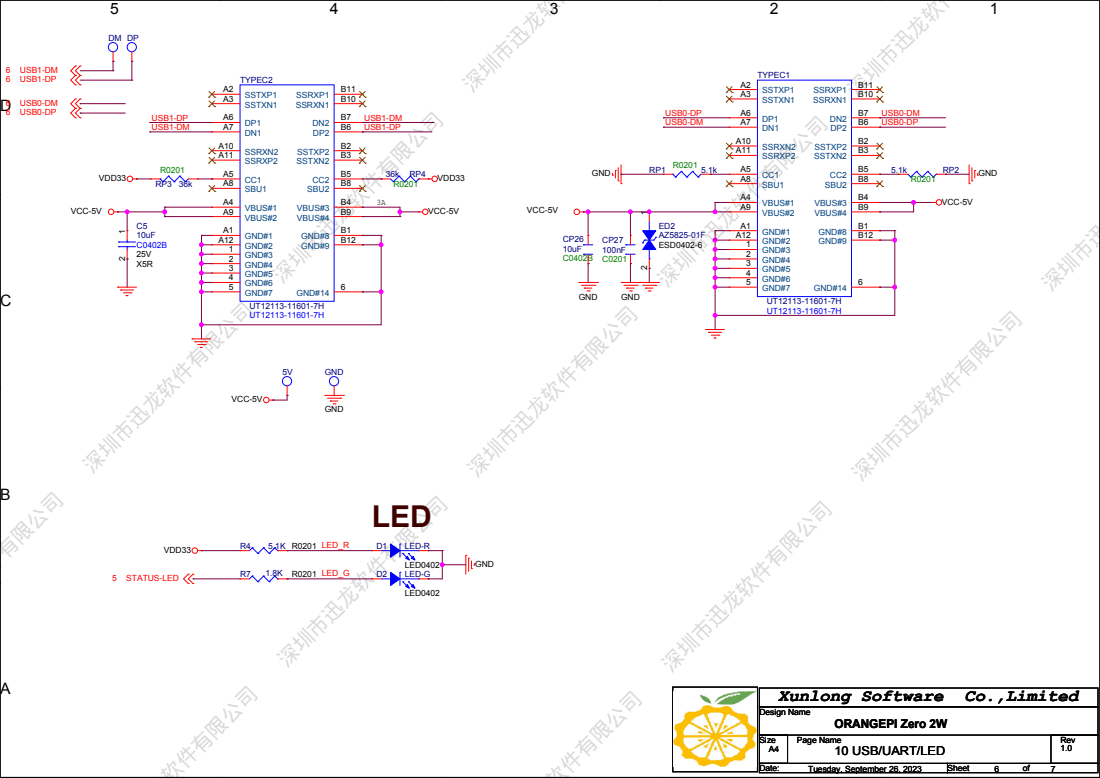
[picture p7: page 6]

深圳市迅龙软件有限公司 深圳市迅龙软件有限公司 深圳市迅龙软件有限公司 深圳市迅龙软件有限公司 深圳市迅龙软件有限公司 深圳市迅龙软件有限公司 深圳市迅龙软件有限公司 深圳市迅龙软件有限公司 深圳市迅龙软件有限公司 深圳市迅龙软件有限公司 深圳市迅龙软件有限公司 深圳市迅龙软件有限公司 深圳市迅龙软件有限公司 深圳市迅龙软件有限公司 深圳市迅龙软件有限公司

Xunlong Software Co.,Limited

D | D

# WIFI+BT

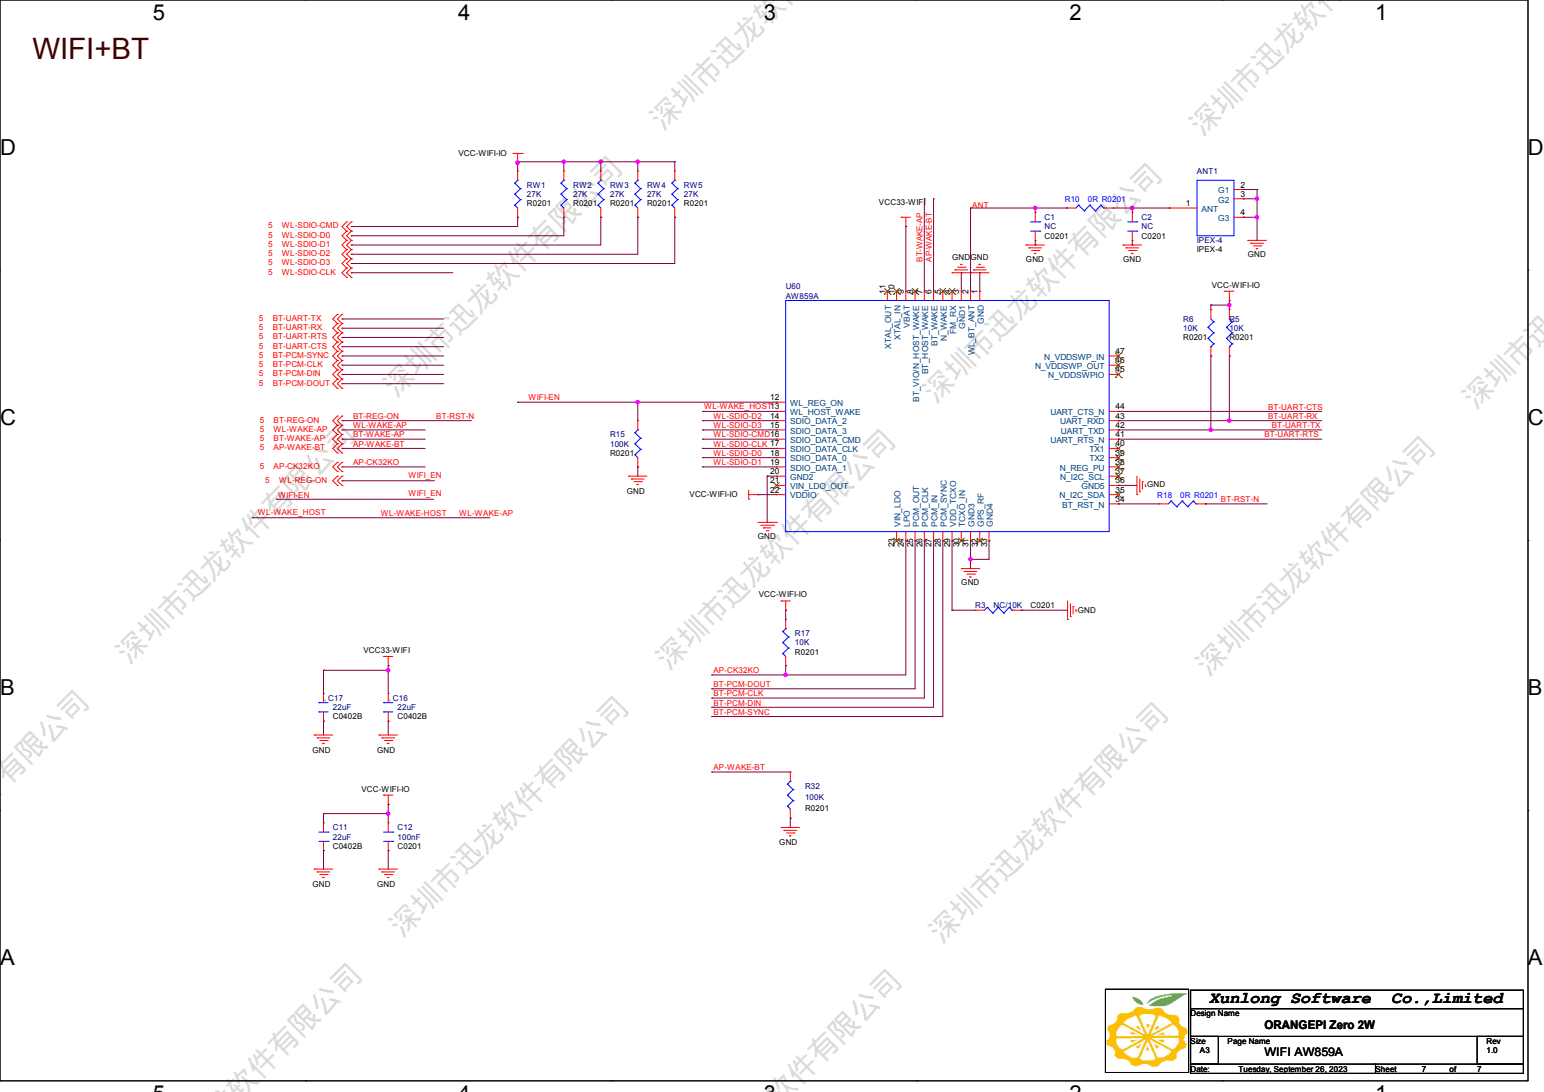
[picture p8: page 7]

深圳市迅龙软件有限公司 深圳市迅龙软件有限公司 深圳市迅龙软件有限公司 深圳市迅龙软件有限公司 深圳市迅龙软件有限公司 深圳市迅龙软件有限公司 深圳市迅龙软件有限公司 深圳市迅龙软件有限公司 深圳市迅龙软件有限公司 深圳市迅龙软件有限公司 深圳市迅龙软件有限公司 深圳市迅龙软件有限公司 深圳市迅龙软件有限公司 深圳市迅龙软件有限公司 深圳市迅龙软件有限公司

Xunlong Software Co.,Limited

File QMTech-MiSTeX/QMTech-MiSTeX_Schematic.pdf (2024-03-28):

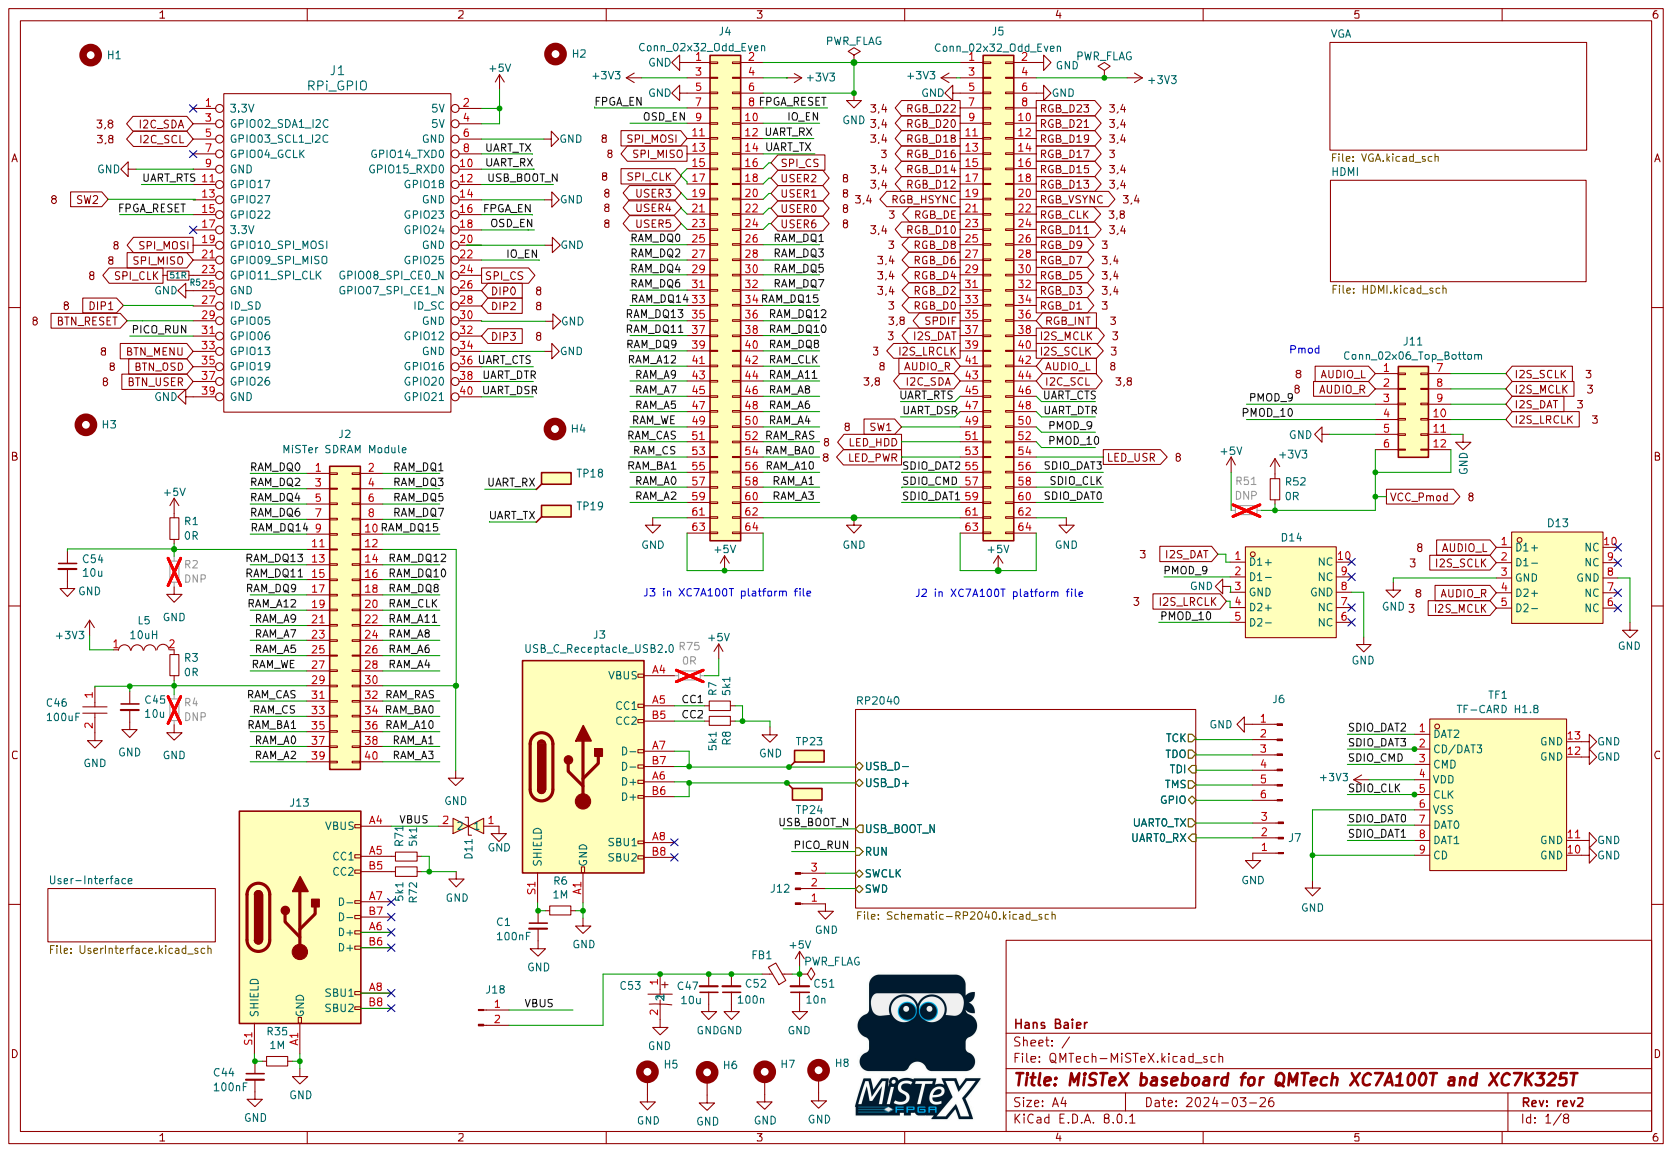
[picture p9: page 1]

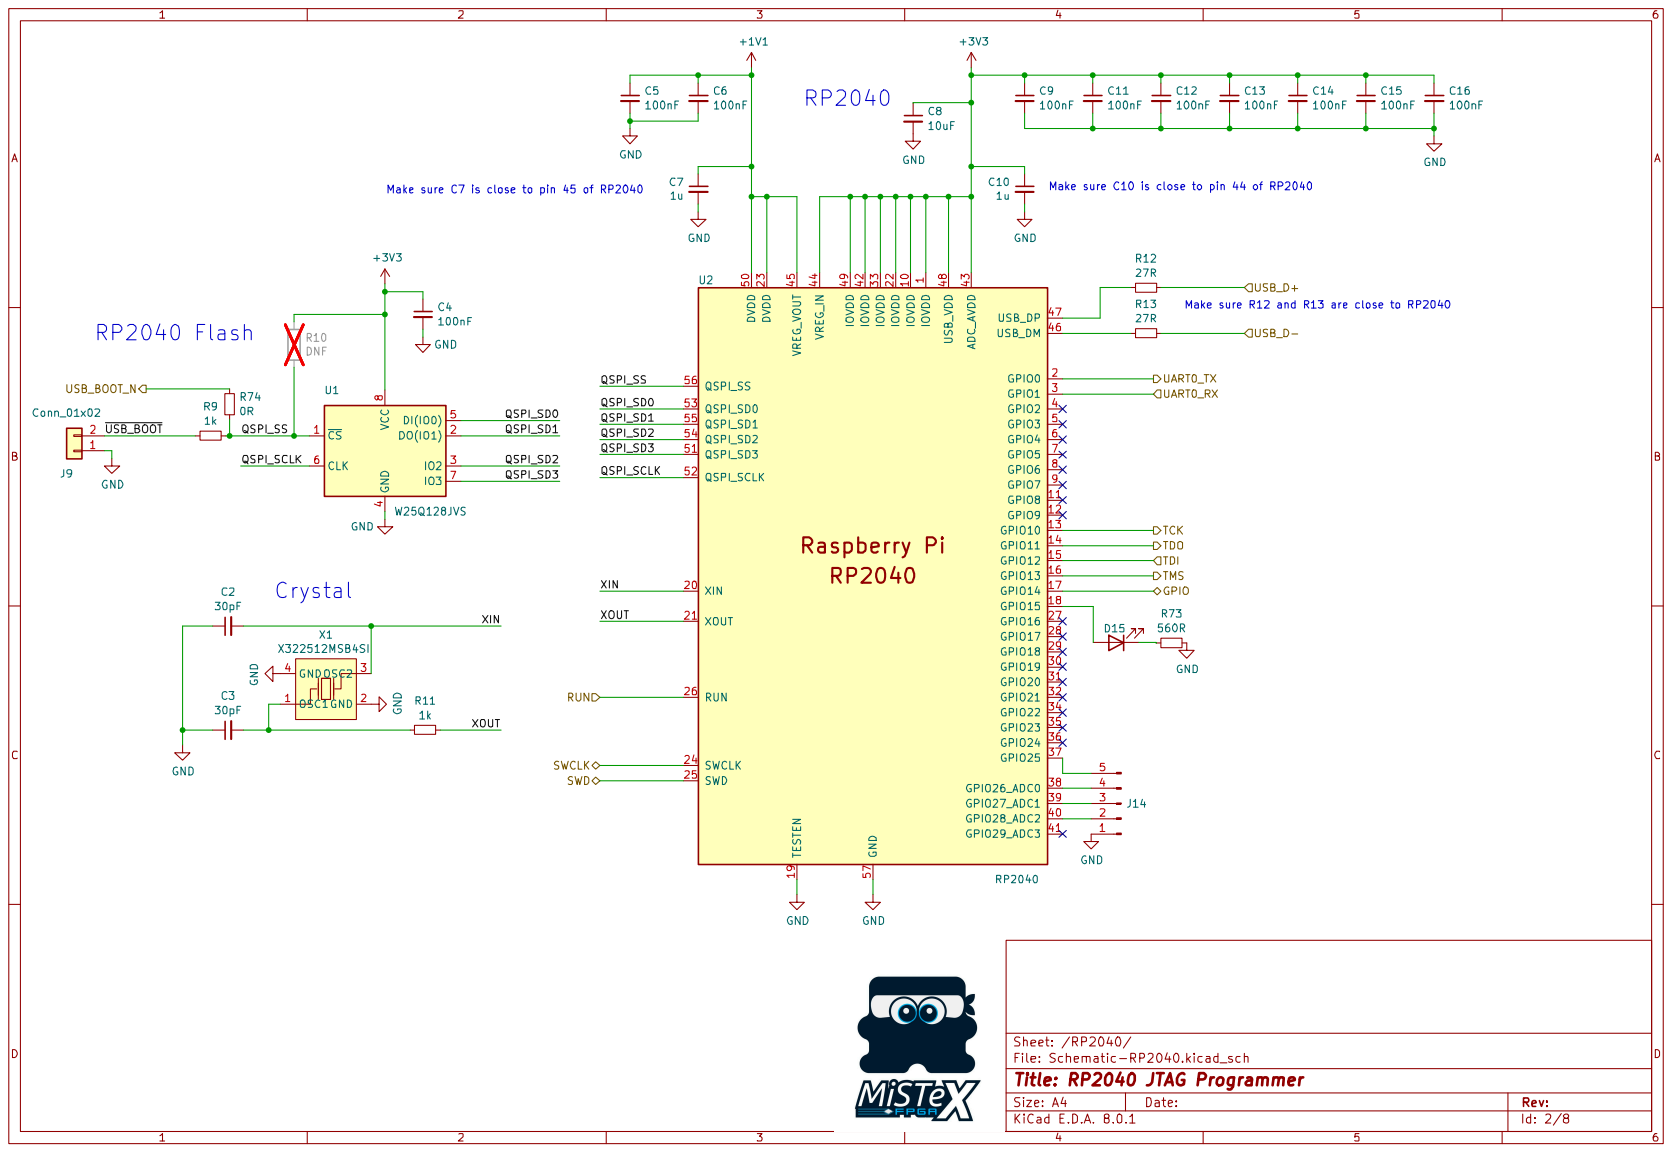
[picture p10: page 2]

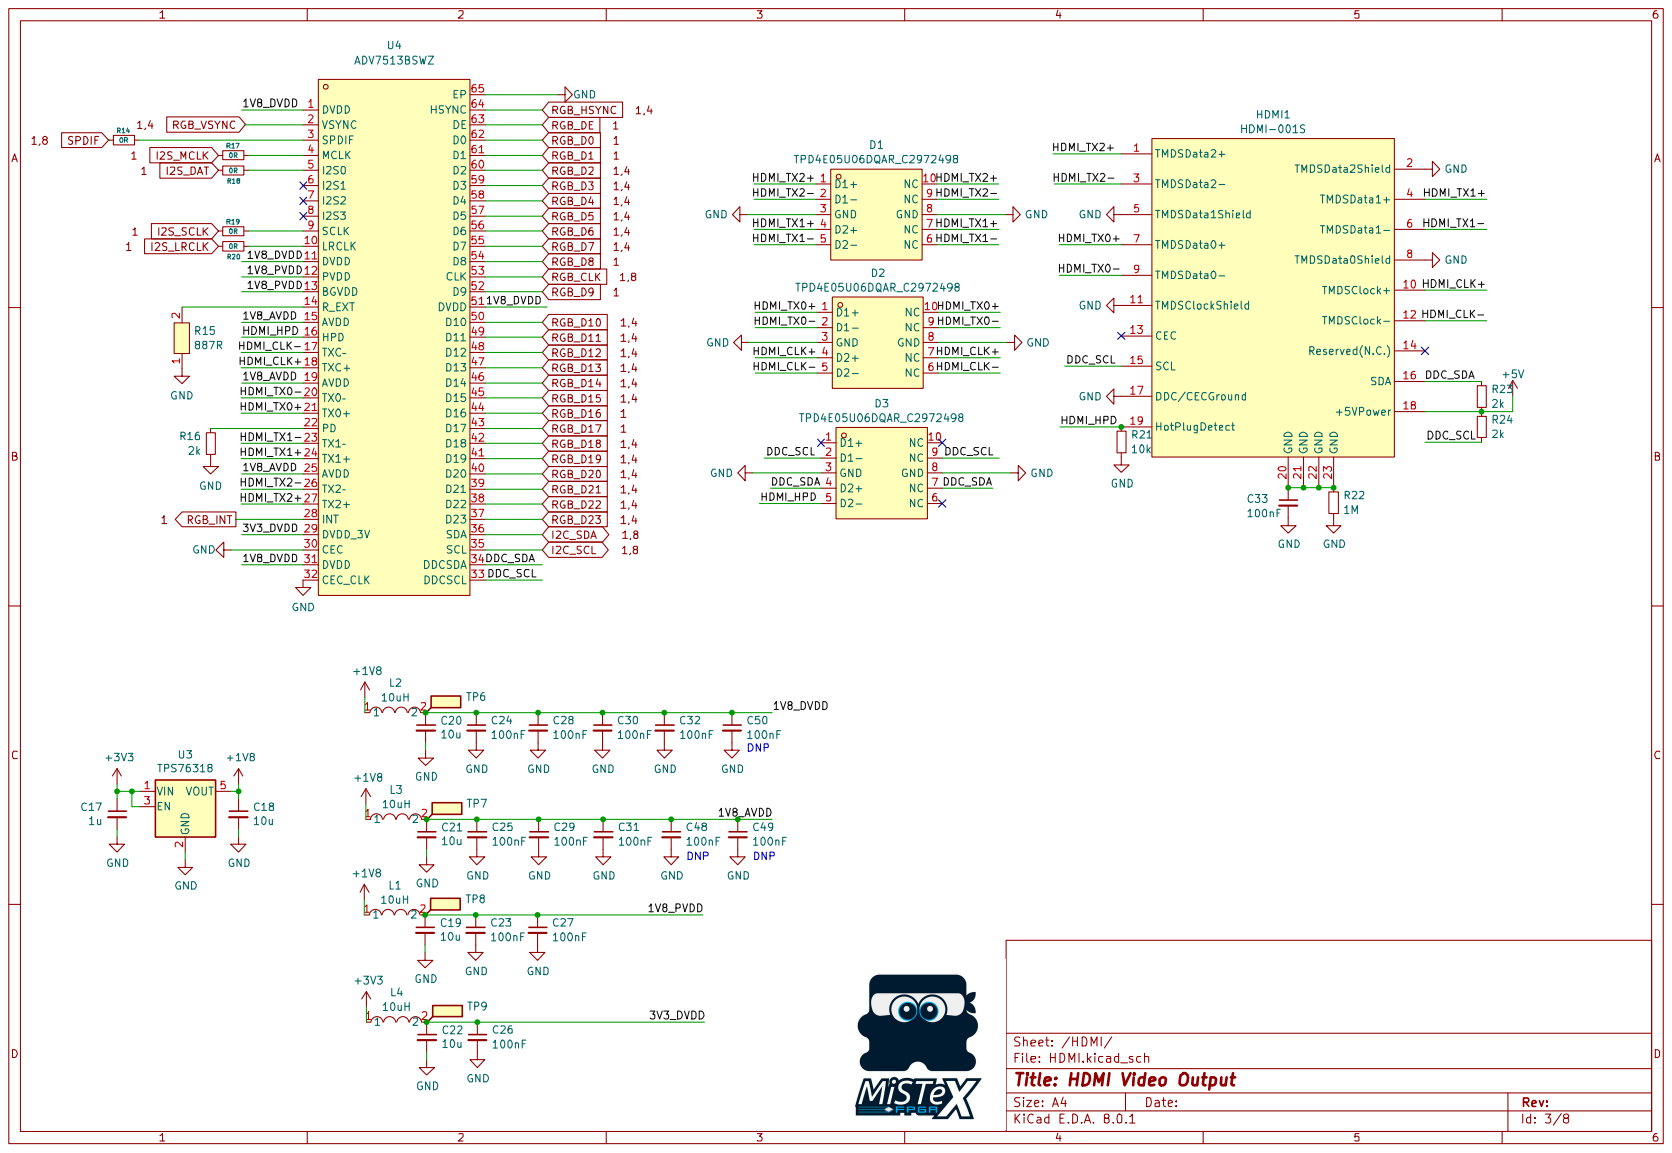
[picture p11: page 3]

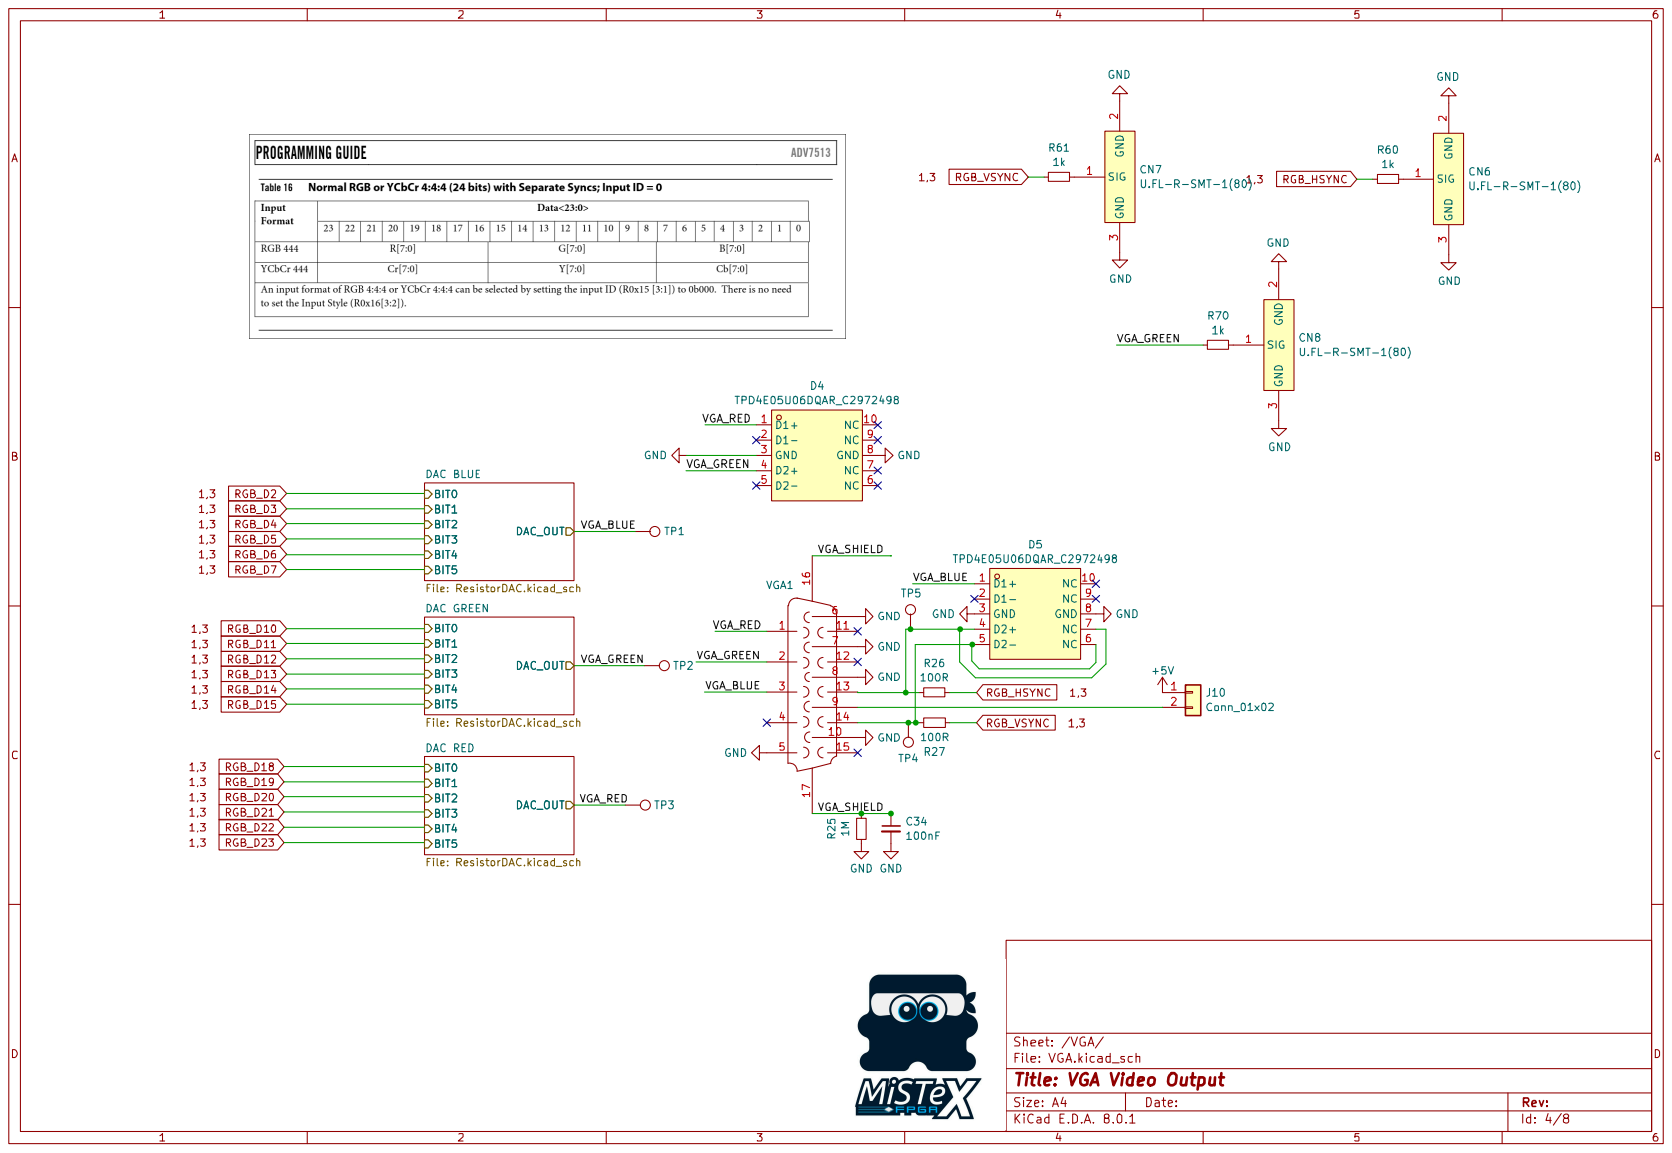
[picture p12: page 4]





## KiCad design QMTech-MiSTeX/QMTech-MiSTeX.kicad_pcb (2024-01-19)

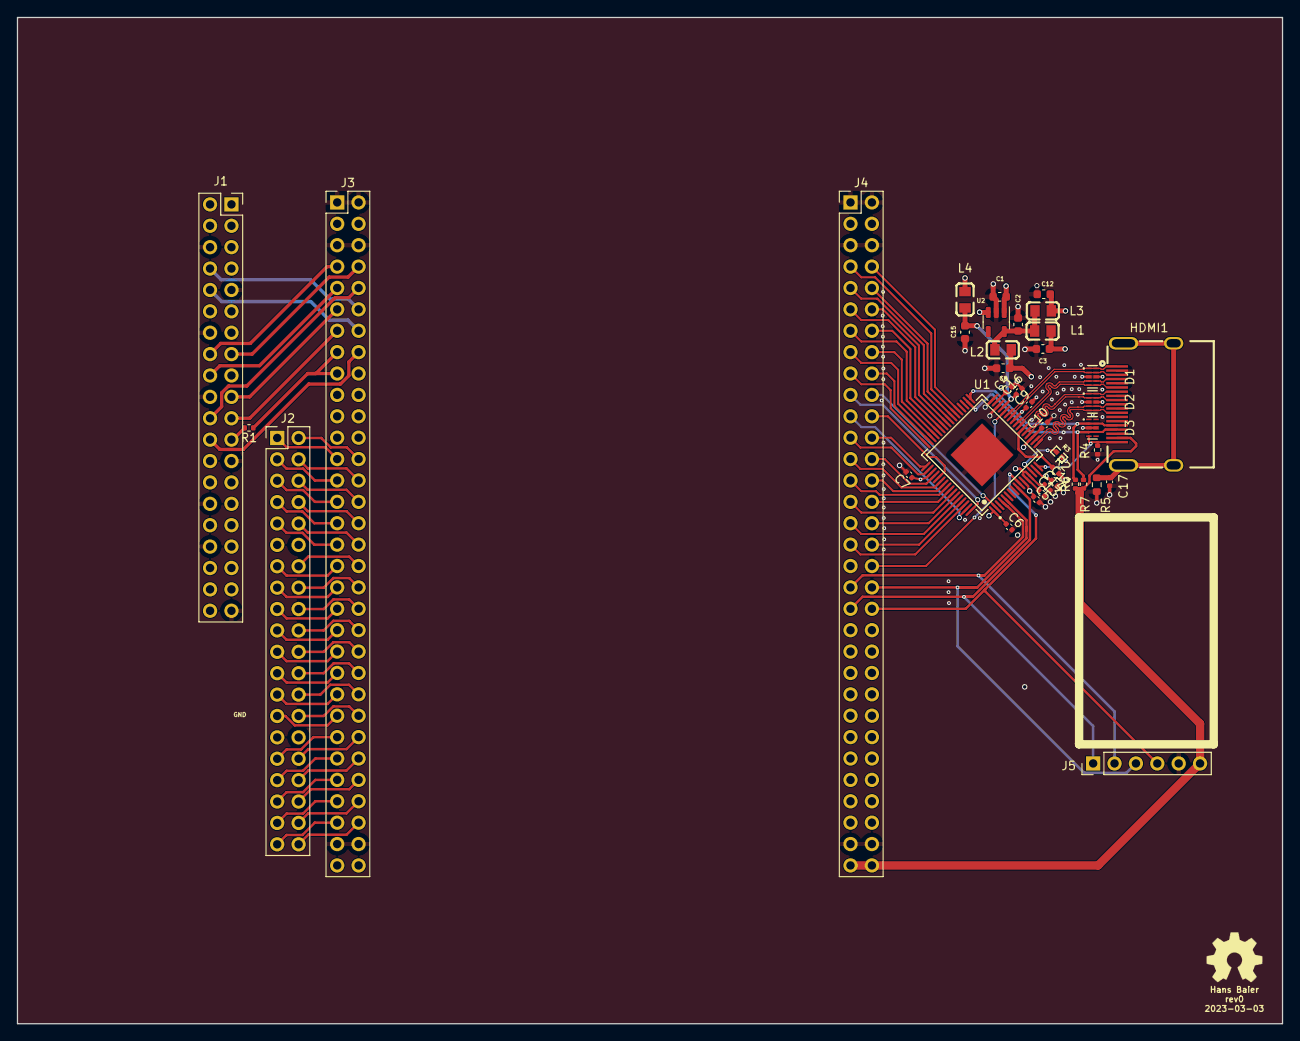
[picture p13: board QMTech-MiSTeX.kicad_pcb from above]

Board: 4 copper layers, 150.2 x 119.5 mm, 40 parts (0 on the bottom side), 104 nets.

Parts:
C1: 1u; C_0603_1608Metric
C2, C3, C8, C12, C15: 10u; C_0603_1608Metric
C4, C5, C6, C7, C9, C10, C11, C13, C14, C16, C17: 100nF; C_0402_1005Metric
D1, D2, D3: TPD4E05U06DQAR_C2972498; DFN2510-10_L2.5-W1.0-P0.50-BL
HDMI1: HDMI-001S; HDMI-SMD_HDMI-001S
J1: RPi_GPIO; PinSocket_2x20_P2.54mm_Vertical
J2: MiSTer SDRAM Module; PinHeader_2x20_P2.54mm_Vertical
J3, J4: Conn_02x32_Odd_Even; PinHeader_2x32_P2.54mm_Vertical
J5: Conn_01x06_Male; PinHeader_1x06_P2.54mm_Vertical
L1, L2, L3, L4: 10uH; L0805
N1: OHWLOGO; OSHW-Symbol_6.7x6mm_SilkScreen
R1: 51R; R_0402_1005Metric
R2, R6, R7: 2k; R_0402_1005Metric
R3: 887R; R0402
R4: 10k; R_0402_1005Metric
R5: 1M; R_0603_1608Metric
U1: ADV7513BSWZ; LQFP-64_L10.0-W10.0-P0.50-LS12.0-BL-EP5.3
U2: TPS76318; SOT-23-5

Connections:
+1V8: C2.1, L1.1, L2.1, L3.1, U2.5 (VOUT)
+3V3: C1.1, J2.29, J3.3, J3.4, J4.3, J4.4, L4.1, U2.1 (VIN), U2.3 (EN)
+5V: HDMI1.18 (+5VPower), J1.2 (5V), J1.4 (5V), J2.11, J3.63, J3.64, J4.63, J4.64, J5.6, R6.1, R7.2
/1V8_AVDD: C8.1, C9.1, C10.1, C11.1, L2.2, U1.15 (AVDD), U1.19 (AVDD), U1.25 (AVDD)
/1V8_DVDD: C3.1, C4.1, C5.1, C6.1, C7.1, L1.2, U1.1 (DVDD), U1.11 (DVDD), U1.31 (DVDD), U1.51 (DVDD)
/1V8_PVDD: C12.1, C13.1, C14.1, L3.2, U1.12 (PVDD), U1.13 (BGVDD)
/3V3_DVDD: C15.1, C16.1, L4.2, U1.29 (DVDD_3V)
/DDC_SCL: D3.2 (D1-), D3.9 (NC), HDMI1.15 (SCL), R6.2, U1.33 (DDCSCL)
/DDC_SDA: D3.4 (D2+), D3.7 (NC), HDMI1.16 (SDA), R7.1, U1.34 (DDCSDA)
/FPGA_EN: J1.16 (GPIO23), J3.7
/FPGA_RESET: J1.15 (GPIO22), J3.8
/HDMI_CLK+: D2.4 (D2+), D2.7 (NC), HDMI1.10 (TMDSClock+), U1.18 (TXC+)
/HDMI_CLK-: D2.5 (D2-), D2.6 (NC), HDMI1.12 (TMDSClock-), U1.17 (TXC–)
/HDMI_HPD: D3.5 (D2-), HDMI1.19 (HotPlugDetect), R4.1, U1.16 (HPD)
/HDMI_TX0+: D2.1 (D1+), D2.10 (NC), HDMI1.7 (TMDSData0+), U1.21 (TX0+)
/HDMI_TX0-: D2.2 (D1-), D2.9 (NC), HDMI1.9 (TMDSData0-), U1.20 (TX0–)
/HDMI_TX1+: D1.4 (D2+), D1.7 (NC), HDMI1.4 (TMDSData1+), U1.24 (TX1+)
/HDMI_TX1-: D1.5 (D2-), D1.6 (NC), HDMI1.6 (TMDSData1-), U1.23 (TX1–)
/HDMI_TX2+: D1.1 (D1+), D1.10 (NC), HDMI1.1 (TMDSData2+), U1.27 (TX2+)
/HDMI_TX2-: D1.2 (D1-), D1.9 (NC), HDMI1.3 (TMDSData2-), U1.26 (TX2–)
/I2C_SCL: J1.5 (GPIO03_SCL1_I2C), U1.35 (SCL)
/I2C_SDA: J1.3 (GPIO02_SDA1_I2C), U1.36 (SDA)
/I2S_DAT: J4.38, J5.3, U1.5 (I2S0)
/I2S_LRCLK: J4.40, J5.4, U1.10 (LRCLK)
/I2S_MCLK: J4.37, J5.2, U1.4 (MCLK)
/I2S_SCLK: J4.39, J5.1, U1.9 (SCLK)
/IO_EN: J1.22 (GPIO25), J3.10
/OSD_EN: J1.18 (GPIO24), J3.9
/RAM_A0: J2.37, J3.57
/RAM_A1: J2.38, J3.58
/RAM_A2: J2.39, J3.59
/RAM_A3: J2.40, J3.60
/RAM_A4: J2.28, J3.50
/RAM_A5: J2.25, J3.47
/RAM_A6: J2.26, J3.48
/RAM_A7: J2.23, J3.45
/RAM_A8: J2.24, J3.46
/RAM_A9: J2.21, J3.43
/RAM_A10: J2.36, J3.56
/RAM_A11: J2.22, J3.44
/RAM_A12: J2.19, J3.41
/RAM_BA0: J2.34, J3.54
/RAM_BA1: J2.35, J3.55
/RAM_CAS: J2.31, J3.51
/RAM_CLK: J2.20, J3.42
/RAM_CS: J2.33, J3.53
/RAM_DQ0: J2.1, J3.25
/RAM_DQ1: J2.2, J3.26
/RAM_DQ2: J2.3, J3.27
/RAM_DQ3: J2.4, J3.28
/RAM_DQ4: J2.5, J3.29
/RAM_DQ5: J2.6, J3.30
/RAM_DQ6: J2.7, J3.31
/RAM_DQ7: J2.8, J3.32
/RAM_DQ8: J2.18, J3.40
/RAM_DQ9: J2.17, J3.39
/RAM_DQ10: J2.16, J3.38
/RAM_DQ11: J2.15, J3.37
/RAM_DQ12: J2.14, J3.36
/RAM_DQ13: J2.13, J3.35
/RAM_DQ14: J2.10, J3.34
/RAM_DQ15: J2.9, J3.33
/RAM_RAS: J2.32, J3.52
/RAM_WE: J2.27, J3.49
/RGB_CLK: J4.22, U1.53 (CLK)
/RGB_D0: J4.33, U1.62 (D0)
/RGB_D1: J4.34, U1.61 (D1)
/RGB_D2: J4.31, U1.60 (D2)
/RGB_D3: J4.32, U1.59 (D3)
/RGB_D4: J4.29, U1.58 (D4)
/RGB_D5: J4.30, U1.57 (D5)
/RGB_D6: J4.27, U1.56 (D6)
/RGB_D7: J4.28, U1.55 (D7)
/RGB_D8: J4.25, U1.54 (D8)
/RGB_D9: J4.26, U1.52 (D9)
/RGB_D10: J4.23, U1.50 (D10)
/RGB_D11: J4.24, U1.49 (D11)
/RGB_D12: J4.17, U1.48 (D12)
/RGB_D13: J4.18, U1.47 (D13)
/RGB_D14: J4.15, U1.46 (D14)
/RGB_D15: J4.16, U1.45 (D15)
/RGB_D16: J4.13, U1.44 (D16)
/RGB_D17: J4.14, U1.43 (D17)
/RGB_D18: J4.11, U1.42 (D18)
/RGB_D19: J4.12, U1.41 (D19)
/RGB_D20: J4.9, U1.40 (D20)
/RGB_D21: J4.10, U1.39 (D21)
/RGB_D22: J4.7, U1.38 (D22)
/RGB_D23: J4.8, U1.37 (D23)
/RGB_DE: J4.21, U1.63 (DE)
/RGB_HSYNC: J4.19, U1.64 (HSYNC)
/RGB_INT: J4.36, U1.28 (INT)
/RGB_VSYNC: J4.20, U1.2 (VSYNC)
/SPI_CLK: J3.15, J3.17, R1.1
/SPI_CS: J1.24 (GPIO08_SPI_CE0_N), J3.16
/SPI_MISO: J1.21 (GPIO09_SPI_MISO), J3.13
/SPI_MOSI: J1.19 (GPIO10_SPI_MOSI), J3.11
/UART_RX: J1.10 (GPIO15_RXD0), J3.14
/UART_TX: J1.8 (GPIO14_TXD0), J3.12
GND: C1.2, C2.2, C3.2, C4.2, C5.2, C6.2, C7.2, C8.2, C9.2, C10.2, C11.2, C12.2, C13.2, C14.2, C15.2, C16.2, C17.2, D1.3 (GND), D1.8 (GND), D2.3 (GND), D2.8 (GND), D3.3 (GND), D3.8 (GND), HDMI1.2 (TMDSData2Shield), HDMI1.5 (TMDSData1Shield), HDMI1.8 (TMDSData0Shield), HDMI1.11 (TMDSClockShield), HDMI1.17 (DDC/CECGround), J1.6 (GND), J1.9 (GND), J1.14 (GND), J1.20 (GND), J1.25 (GND), J1.30 (GND), J1.34 (GND), J1.39 (GND), J2.12, J2.30, J3.1, J3.2, J3.5, J3.6, J3.61, J3.62, J4.1, J4.2, J4.5, J4.6, J4.61, J4.62, J5.5, R2.2, R3.1, R4.2, R5.2, U1.30 (CEC), U1.32 (CEC_CLK), U1.65 (EP), U2.2 (GND)
unnamed: C17.1, HDMI1.20 (GND), HDMI1.21 (GND), HDMI1.22 (GND), HDMI1.23 (GND), R5.1
unnamed: J1.23 (GPIO11_SPI_CLK), R1.2
unnamed: R2.1, U1.22 (PD)
unnamed: R3.2, U1.14 (R_EXT)

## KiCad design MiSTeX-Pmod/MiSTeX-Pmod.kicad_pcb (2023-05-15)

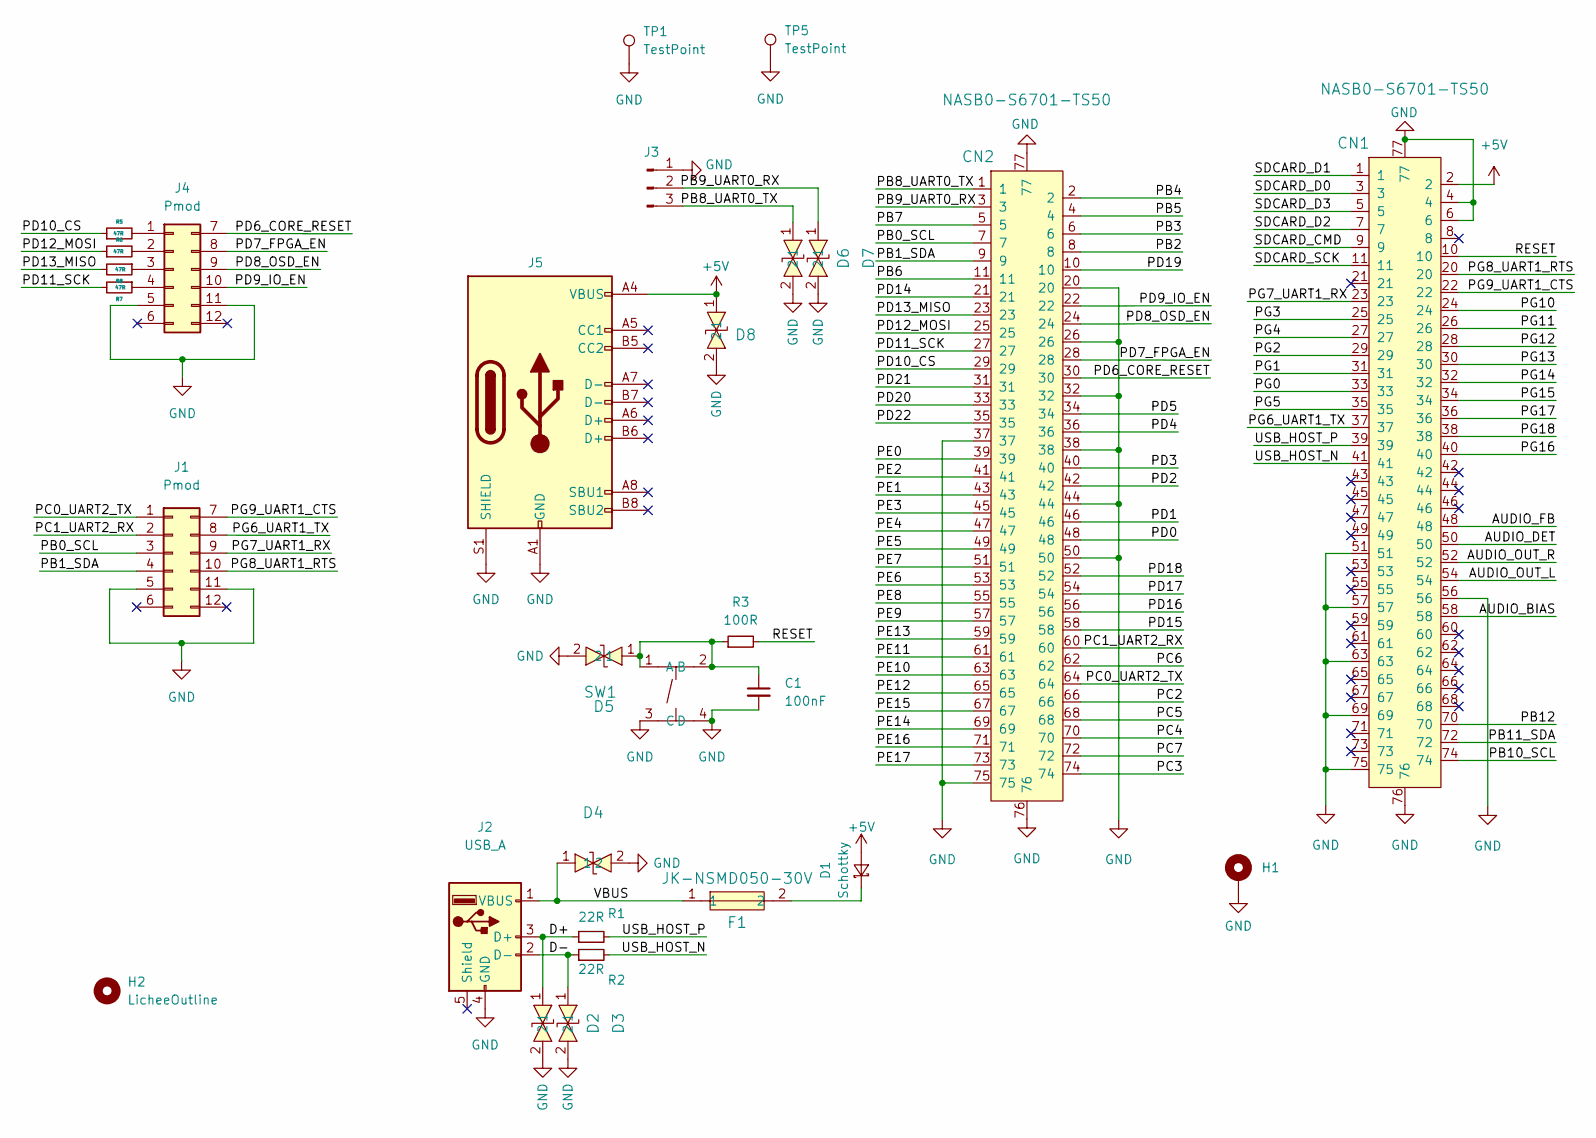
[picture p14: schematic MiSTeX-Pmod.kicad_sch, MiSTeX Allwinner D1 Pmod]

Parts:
C1: 100nF; C_0402_1005Metric; LCSC C1525
CN1, CN2: NASB0-S6701-TS50; CONN-SMD_67P-P0.50-V_NASB0-S6701-TS50; LCSC Part C367024
D1: Schottky; D_SMA; LCSC C22452
D2, D3, D4, D5, D6, D7, D8: LXES15AAA1-133; D0402-BI; LCSC Part C191267
F1: JK-NSMD050-30V; F1206; LCSC Part C720075
H1: MountingHole_Pad; MountingHole_2.2mm_M2_ISO7380_Pad_TopBottom
H2: LicheeOutline
J1, J4: Pmod; Pmod 2x6
J2: USB_A; USB-A-SMD_GT-USB-2004-CWG1A; LCSC C5117890
J3: Conn_01x03_Male; PinHeader_1x03_P2.54mm_Vertical
J5: Connector_USB_C_Receptacle_USB2.0; USB-C_SMD-TYPE-C-31-M-12; LCSC C165948
R1, R2: 22R; R_0402_1005Metric; LCSC C25092
R3: 100R; R_0402_1005Metric; LCSC C25076
R5, R6, R7, R8: 47R; R_0402_1005Metric; LCSC C25118
SW1: TS-1187A-B-A-B; SW-SMD_4P-L5.1-W5.1-P3.70-LS6.5-TL-2; LCSC Part C318884
TP1: TestPoint; TestPoint_Pad_D2.0mm
TP5: TestPoint; TestPoint_Pad_D1.0mm

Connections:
+5V: CN1.2, D1.2 (A), D8.1, J5.A4 (VBUS), J5.A9 (VBUS), J5.B4 (VBUS), J5.B9 (VBUS)
/AUDIO_BIAS: CN1.58
/AUDIO_DET: CN1.50
/AUDIO_FB: CN1.48
/AUDIO_OUT_L: CN1.54
/AUDIO_OUT_R: CN1.52
/D+: D2.1, J2.3 (D+), R1.1
/D-: D3.1, J2.2 (D-), R2.1
/PB0_SCL: CN2.7, J1.3
/PB1_SDA: CN2.9, J1.4
/PB2: CN2.8
/PB3: CN2.6
/PB4: CN2.2
/PB5: CN2.4
/PB6: CN2.11
/PB7: CN2.5
/PB8_UART0_TX: CN2.1, D6.1, J3.3
/PB9_UART0_RX: CN2.3, D7.1, J3.2
/PB10_SCL: CN1.74
/PB11_SDA: CN1.72
/PB12: CN1.70
/PC0_UART2_TX: CN2.64, J1.1
/PC1_UART2_RX: CN2.60, J1.2
/PC2: CN2.66
/PC3: CN2.74
/PC4: CN2.70
/PC5: CN2.68
/PC6: CN2.62
/PC7: CN2.72
/PD0: CN2.48
/PD1: CN2.46
/PD2: CN2.42
/PD3: CN2.40
/PD4: CN2.36
/PD5: CN2.34
/PD6_CORE_RESET: CN2.30, J4.7
/PD7_FPGA_EN: CN2.28, J4.8
/PD8_OSD_EN: CN2.24, J4.9
/PD9_IO_EN: CN2.22, J4.10
/PD10_CS: CN2.29, R5.1
/PD11_SCK: CN2.27, R7.2
/PD12_MOSI: CN2.25, R6.1
/PD13_MISO: CN2.23, R8.2
/PD14: CN2.21
/PD15: CN2.58
/PD16: CN2.56
/PD17: CN2.54
/PD18: CN2.52
/PD19: CN2.10
/PD20: CN2.33
/PD21: CN2.31
/PD22: CN2.35
/PE0: CN2.39
/PE1: CN2.43
/PE2: CN2.41
/PE3: CN2.45
/PE4: CN2.47
/PE5: CN2.49
/PE6: CN2.53
/PE7: CN2.51
/PE8: CN2.55
/PE9: CN2.57
/PE10: CN2.63
/PE11: CN2.61
/PE12: CN2.65
/PE13: CN2.59
/PE14: CN2.69
/PE15: CN2.67
/PE16: CN2.71
/PE17: CN2.73
/PG0: CN1.33
/PG1: CN1.31
/PG2: CN1.29
/PG3: CN1.25
/PG4: CN1.27
/PG5: CN1.35
/PG6_UART1_TX: CN1.37, J1.8
/PG7_UART1_RX: CN1.23, J1.9
/PG8_UART1_RTS: CN1.20, J1.10
/PG9_UART1_CTS: CN1.22, J1.7
/PG10: CN1.24
/PG11: CN1.26
/PG12: CN1.28
/PG13: CN1.30
/PG14: CN1.32
/PG15: CN1.34
/PG16: CN1.40
/PG17: CN1.36
/PG18: CN1.38
/RESET: CN1.10, R3.2
/SDCARD_CMD: CN1.9
/SDCARD_D0: CN1.3
/SDCARD_D1: CN1.1
/SDCARD_D2: CN1.7
/SDCARD_D3: CN1.5
/SDCARD_SCK: CN1.11
/USB_HOST_N: CN1.41, R2.2
/USB_HOST_P: CN1.39, R1.2
/VBUS: D4.1, F1.1, J2.1 (VBUS)
GND: C1.2, CN1.4, CN1.6, CN1.51, CN1.56, CN1.57, CN1.63, CN1.69, CN1.75, CN1.76, CN1.77, CN2.20, CN2.26, CN2.32, CN2.37, CN2.38, CN2.44, CN2.50, CN2.75, CN2.76, CN2.77, D2.2, D3.2, D4.2, D5.2, D6.2, D7.2, D8.2, H1.1, J1.5, J1.11, J2.4 (GND), J3.1, J4.5, J4.11, J5.A1 (GND), J5.A12 (GND), J5.B1 (GND), J5.B12 (GND), J5.S1 (SHIELD), SW1.3 (C), SW1.4 (D), TP1.1, TP5.1
unnamed: C1.1, D5.1, R3.1, SW1.1 (A), SW1.2 (B)
unnamed: D1.1 (K), F1.2
unnamed: J4.1, R5.2
unnamed: J4.2, R6.2
unnamed: J4.3, R8.1
unnamed: J4.4, R7.1

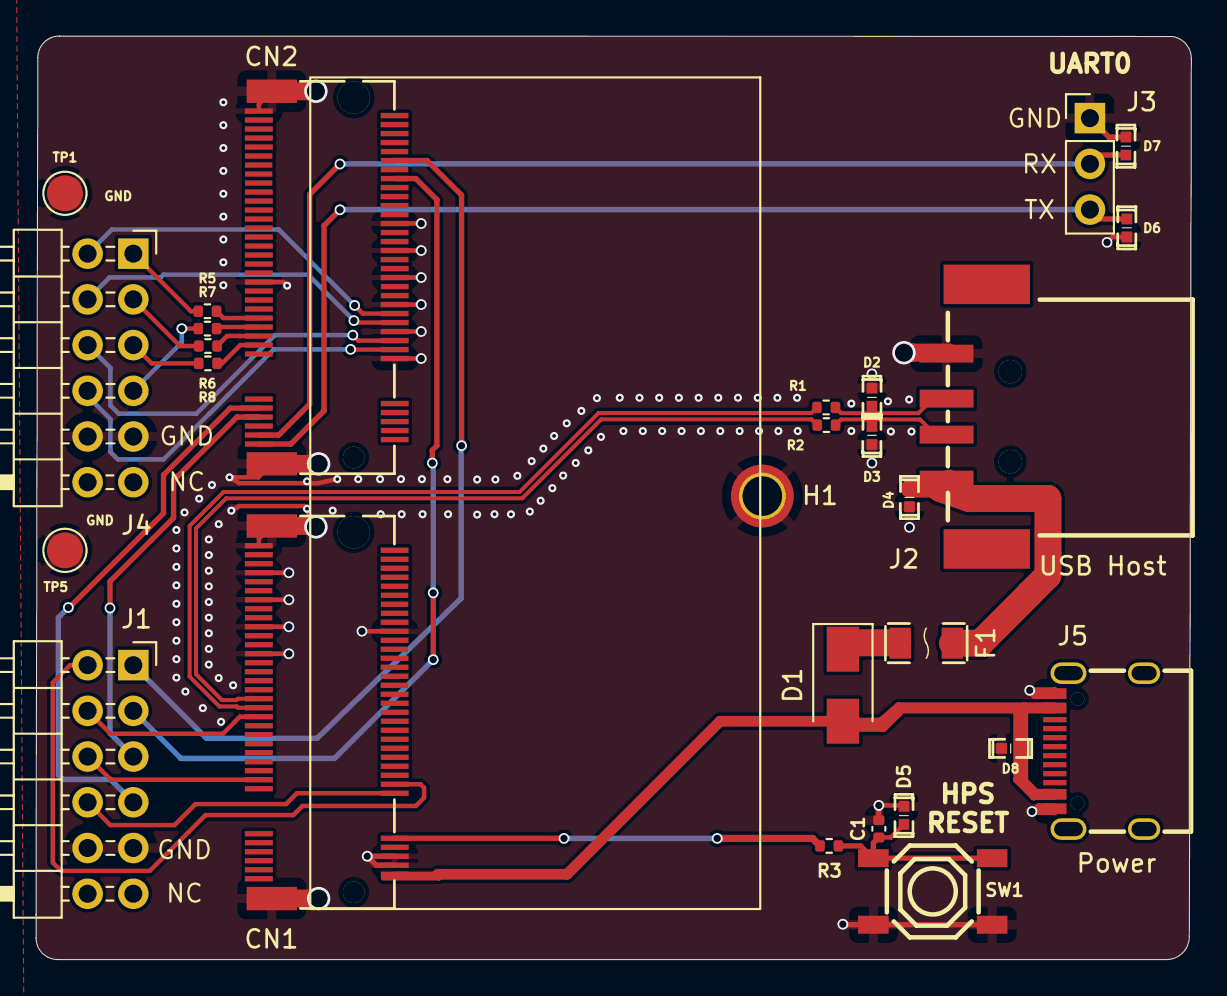
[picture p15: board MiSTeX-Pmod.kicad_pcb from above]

Board: 4 copper layers, 64.2 x 51.3 mm, 30 parts (0 on the bottom side), 32 nets.

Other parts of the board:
N1: OHWLOGO; OSHW-Symbol_6.7x6mm_SilkScreen

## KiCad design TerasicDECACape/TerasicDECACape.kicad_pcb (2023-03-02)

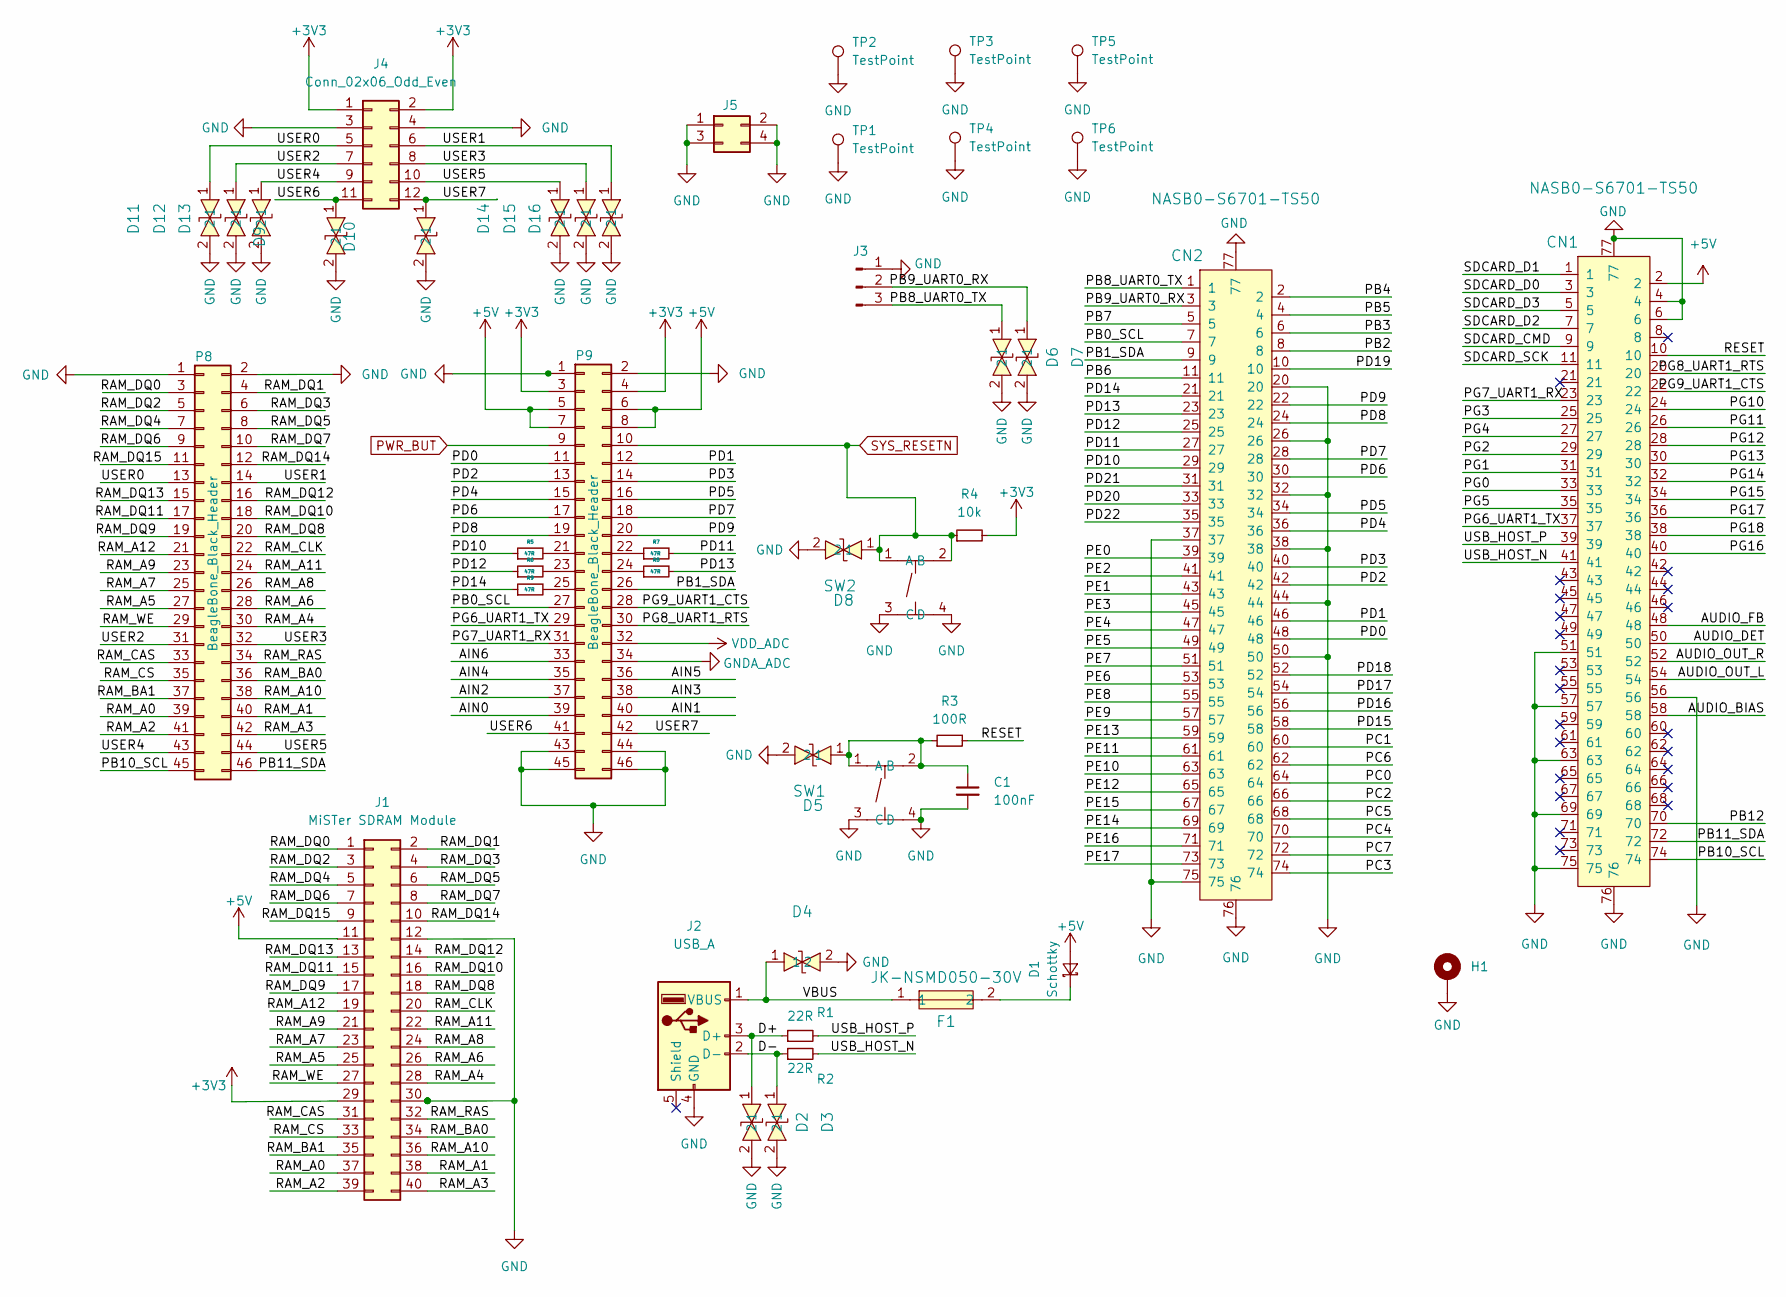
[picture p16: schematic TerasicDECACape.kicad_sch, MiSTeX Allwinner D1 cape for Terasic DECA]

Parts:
C1: 100nF; C_0402_1005Metric; LCSC C1525
CN1, CN2: NASB0-S6701-TS50; CONN-SMD_67P-P0.50-V_NASB0-S6701-TS50; LCSC Part C367024
D1: Schottky; D_SMA; LCSC C22452
D2, D3, D4, D5, D6, D7, D8, D9, D10, D11, D12, D13, D14, D15, D16: LXES15AAA1-133; D0402-BI; LCSC Part C191267
F1: JK-NSMD050-30V; F1206; LCSC Part C720075
H1: MountingHole_Pad; MountingHole_2.2mm_M2_ISO7380_Pad_TopBottom
J1: MiSTer SDRAM Module; PinHeader_2x20_P2.54mm_Vertical
J2: USB_A; USB-A-SMD_USB-302S; LCSC C112455
J3: Conn_01x03_Male; PinHeader_1x03_P2.54mm_Vertical
J4: Conn_02x06_Odd_Even; PinSocket_2x06_P2.54mm_Vertical
J5: Conn_02x02_Odd_Even; PinHeader_2x02_P2.54mm_Vertical
P8, P9: BeagleBone_Black_Header; Socket_BeagleBone_Black
R1, R2: 22R; R_0402_1005Metric; LCSC C25092
R3: 100R; R_0402_1005Metric; LCSC C25076
R4: 10k; R_0402_1005Metric; LCSC C25744
R5, R6, R7, R8, R9: 47R; R_0402_1005Metric; LCSC C25118
SW1, SW2: TS-1187A-B-A-B; SW-SMD_4P-L5.1-W5.1-P3.70-LS6.5-TL-2; LCSC Part C318884
TP1, TP4: TestPoint; TestPoint_Pad_D2.0mm
TP2, TP3, TP5, TP6: TestPoint; TestPoint_Pad_D1.0mm

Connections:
+3V3: J1.29, J4.1, J4.2, P9.3, P9.4, R4.2
+5V: CN1.2, D1.2 (A), J1.11, P9.5, P9.6, P9.7, P9.8
/AIN0: P9.39
/AIN1: P9.40
/AIN2: P9.37
/AIN3: P9.38
/AIN4: P9.35
/AIN5: P9.36
/AIN6: P9.33
/AUDIO_BIAS: CN1.58
/AUDIO_DET: CN1.50
/AUDIO_FB: CN1.48
/AUDIO_OUT_L: CN1.54
/AUDIO_OUT_R: CN1.52
/D+: D2.1, J2.3 (D+), R1.1
/D-: D3.1, J2.2 (D-), R2.1
/PB0_SCL: CN2.7, P9.27
/PB1_SDA: CN2.9, P9.26
/PB2: CN2.8
/PB3: CN2.6
/PB4: CN2.2
/PB5: CN2.4
/PB6: CN2.11
/PB7: CN2.5
/PB8_UART0_TX: CN2.1, D6.1, J3.3
/PB9_UART0_RX: CN2.3, D7.1, J3.2
/PB10_SCL: CN1.74, P8.45
/PB11_SDA: CN1.72, P8.46
/PB12: CN1.70
/PC0: CN2.64
/PC1: CN2.60
/PC2: CN2.66
/PC3: CN2.74
/PC4: CN2.70
/PC5: CN2.68
/PC6: CN2.62
/PC7: CN2.72
/PD0: CN2.48, P9.11
/PD1: CN2.46, P9.12
/PD2: CN2.42, P9.13
/PD3: CN2.40, P9.14
/PD4: CN2.36, P9.15
/PD5: CN2.34, P9.16
/PD6: CN2.30, P9.17
/PD7: CN2.28, P9.18
/PD8: CN2.24, P9.19
/PD9: CN2.22, P9.20
/PD10: CN2.29, R5.1
/PD11: CN2.27, R7.2
/PD12: CN2.25, R6.1
/PD13: CN2.23, R8.2
/PD14: CN2.21, R9.1
/PD15: CN2.58
/PD16: CN2.56
/PD17: CN2.54
/PD18: CN2.52
/PD19: CN2.10
/PD20: CN2.33
/PD21: CN2.31
/PD22: CN2.35
/PE0: CN2.39
/PE1: CN2.43
/PE2: CN2.41
/PE3: CN2.45
/PE4: CN2.47
/PE5: CN2.49
/PE6: CN2.53
/PE7: CN2.51
/PE8: CN2.55
/PE9: CN2.57
/PE10: CN2.63
/PE11: CN2.61
/PE12: CN2.65
/PE13: CN2.59
/PE14: CN2.69
/PE15: CN2.67
/PE16: CN2.71
/PE17: CN2.73
/PG0: CN1.33
/PG1: CN1.31
/PG2: CN1.29
/PG3: CN1.25
/PG4: CN1.27
/PG5: CN1.35
/PG6_UART1_TX: CN1.37, P9.29
/PG7_UART1_RX: CN1.23, P9.31
/PG8_UART1_RTS: CN1.20, P9.30
/PG9_UART1_CTS: CN1.22, P9.28
/PG10: CN1.24
/PG11: CN1.26
/PG12: CN1.28
/PG13: CN1.30
/PG14: CN1.32
/PG15: CN1.34
/PG16: CN1.40
/PG17: CN1.36
/PG18: CN1.38
/RAM_A0: J1.37, P8.39
/RAM_A1: J1.38, P8.40
/RAM_A2: J1.39, P8.41
/RAM_A3: J1.40, P8.42
/RAM_A4: J1.28, P8.30
/RAM_A5: J1.25, P8.27
/RAM_A6: J1.26, P8.28
/RAM_A7: J1.23, P8.25
/RAM_A8: J1.24, P8.26
/RAM_A9: J1.21, P8.23
/RAM_A10: J1.36, P8.38
/RAM_A11: J1.22, P8.24
/RAM_A12: J1.19, P8.21
/RAM_BA0: J1.34, P8.36
/RAM_BA1: J1.35, P8.37
/RAM_CAS: J1.31, P8.33
/RAM_CLK: J1.20, P8.22
/RAM_CS: J1.33, P8.35
/RAM_DQ0: J1.1, P8.3
/RAM_DQ1: J1.2, P8.4
/RAM_DQ2: J1.3, P8.5
/RAM_DQ3: J1.4, P8.6
/RAM_DQ4: J1.5, P8.7
/RAM_DQ5: J1.6, P8.8
/RAM_DQ6: J1.7, P8.9
/RAM_DQ7: J1.8, P8.10
/RAM_DQ8: J1.18, P8.20
/RAM_DQ9: J1.17, P8.19
/RAM_DQ10: J1.16, P8.18
/RAM_DQ11: J1.15, P8.17
/RAM_DQ12: J1.14, P8.16
/RAM_DQ13: J1.13, P8.15
/RAM_DQ14: J1.10, P8.12
/RAM_DQ15: J1.9, P8.11
/RAM_RAS: J1.32, P8.34
/RAM_WE: J1.27, P8.29
/RESET: CN1.10, R3.2
/SDCARD_CMD: CN1.9
/SDCARD_D0: CN1.3
/SDCARD_D1: CN1.1
/SDCARD_D2: CN1.7
/SDCARD_D3: CN1.5
/SDCARD_SCK: CN1.11
/USB_HOST_N: CN1.41, R2.2
/USB_HOST_P: CN1.39, R1.2
/USER0: D11.1, J4.5, P8.13
/USER1: D16.1, J4.6, P8.14
/USER2: D12.1, J4.7, P8.31
/USER3: D15.1, J4.8, P8.32
/USER4: D13.1, J4.9, P8.43
/USER5: D14.1, J4.10, P8.44
/USER6: D9.1, J4.11, P9.41
/USER7: D10.1, J4.12, P9.42
/VBUS: D4.1, F1.1, J2.1 (VBUS)
GND: C1.2, CN1.4, CN1.6, CN1.51, CN1.56, CN1.57, CN1.63, CN1.69, CN1.75, CN1.76, CN1.77, CN2.20, CN2.26, CN2.32, CN2.37, CN2.38, CN2.44, CN2.50, CN2.75, CN2.76, CN2.77, D2.2, D3.2, D4.2, D5.2, D6.2, D7.2, D8.2, D9.2, D10.2, D11.2, D12.2, D13.2, D14.2, D15.2, D16.2, H1.1, J1.12, J1.30, J2.4 (GND), J3.1, J4.3, J4.4, J5.1, J5.2, J5.3, J5.4, P8.1, P8.2, P9.1, P9.2, P9.43, P9.44, P9.45, P9.46, SW1.3 (C), SW1.4 (D), SW2.3 (C), SW2.4 (D), TP1.1, TP2.1, TP3.1, TP4.1, TP5.1, TP6.1
GNDA_ADC: P9.34
unnamed: C1.1, D5.1, R3.1, SW1.1 (A), SW1.2 (B)
unnamed: D1.1 (K), F1.2
unnamed: P9.21, R5.2
unnamed: P9.22, R7.1
unnamed: P9.23, R6.2
unnamed: P9.24, R8.1
unnamed: P9.25, R9.2
PWR_BUT: P9.9
SYS_RESETN: D8.1, P9.10, R4.1, SW2.1 (A), SW2.2 (B)
VDD_ADC: P9.32

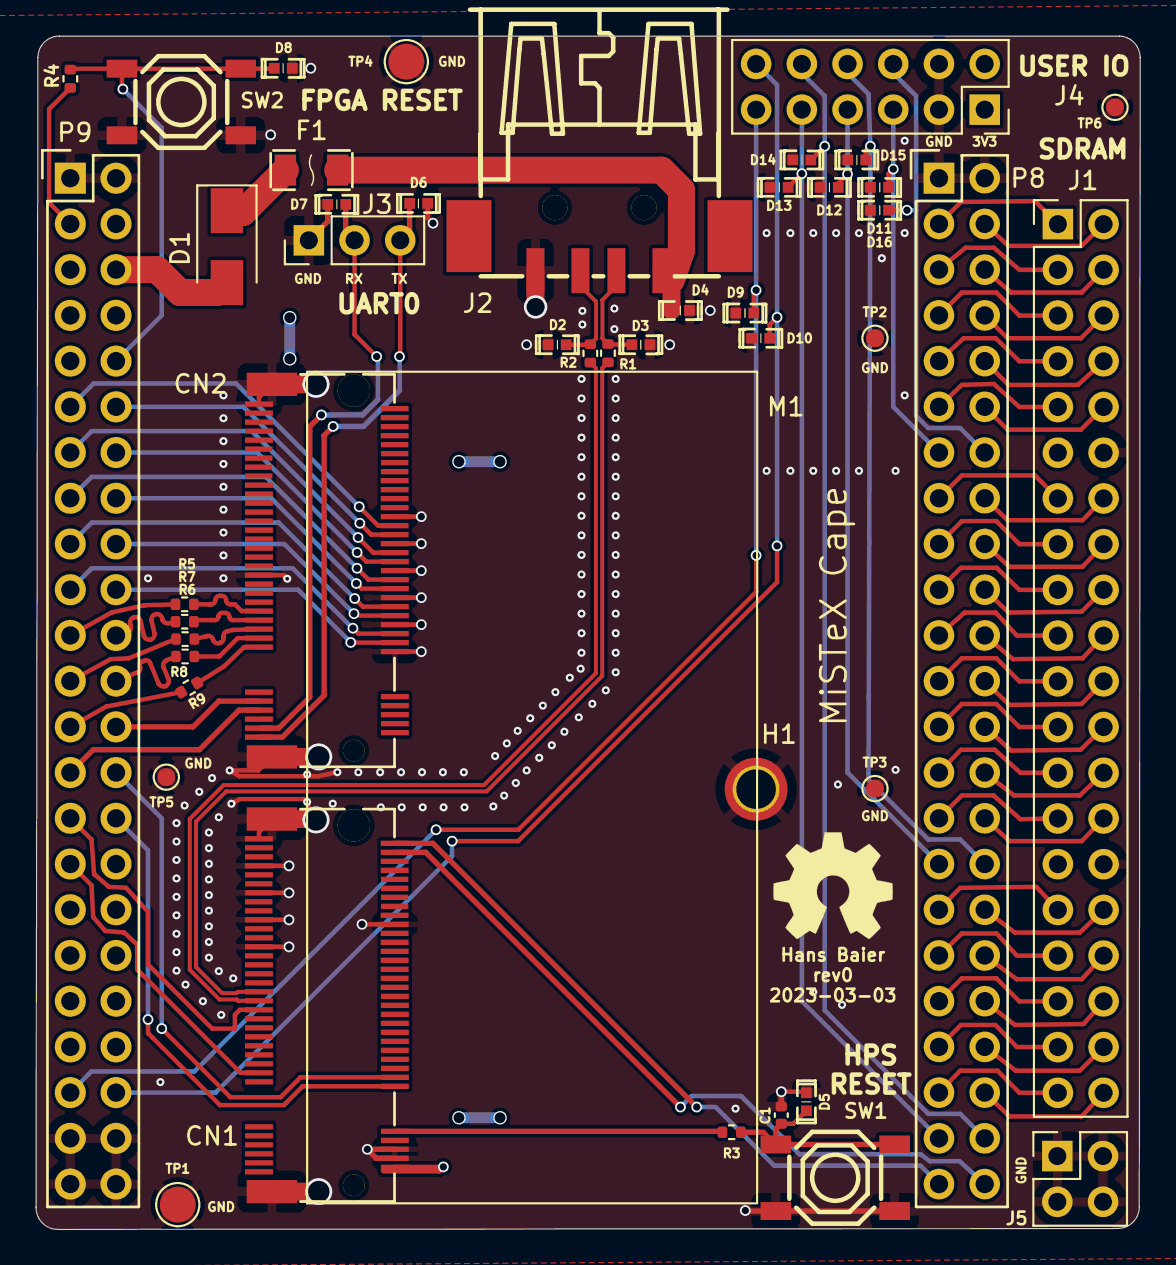
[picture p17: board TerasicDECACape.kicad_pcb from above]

Board: 4 copper layers, 61.3 x 66.3 mm, 47 parts (0 on the bottom side), 86 nets.

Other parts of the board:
M1: Sipeed Lichee
N1: OHWLOGO; OSHW-Symbol_6.7x6mm_SilkScreen

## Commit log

2023-03-01 first take on the board, needs review
    [TerasicDECACape.kicad_pcb, TerasicDECACape.kicad_sch, TerasicDECACape.sch]
2023-03-01 add mounting hole for module
    [TerasicDECACape.kicad_pcb, TerasicDECACape.kicad_sch]
2023-03-01 add user IO header, connect UART1 with flow control
    [TerasicDECACape.kicad_pcb, TerasicDECACape.kicad_sch]
2023-03-01 add title block data
    [TerasicDECACape.kicad_sch]
2023-03-01 fix DRC issues
    [TerasicDECACape.kicad_pcb, TerasicDECACape.kicad_sch]
2023-03-01 add ESD to user header
    [TerasicDECACape.kicad_sch]
2023-03-01 schematic and PCB cosmetics
    [TerasicDECACape.kicad_pcb, TerasicDECACape.kicad_sch]
2023-03-02 remove LEDs, because we have enough on the base board, add their pins to USER IO
    [TerasicDECACape.kicad_pcb, TerasicDECACape.kicad_sch]
2023-03-02 tidy, make it ready for production
    [TerasicDECACape.kicad_pcb]
2023-03-02 fix swapped SDRAM net names on both headers, fix impedance on USB diff pair, add SPI termination resistors
    [TerasicDECACape.kicad_pcb, TerasicDECACape.kicad_sch]
2023-03-02 silkscreen cosmetics
    [TerasicDECACape.kicad_pcb]
2023-03-02 add ground headers, ground test points and ground vias
    [TerasicDECACape.kicad_pcb, TerasicDECACape.kicad_sch]
2023-03-02 silk screen fix
    [TerasicDECACape.kicad_pcb]
2023-03-02 fix tracks running above plane split
    [TerasicDECACape.kicad_pcb]
2023-03-02 Silkscreen: Add board name, credits and OSHW logo
    [TerasicDECACape.kicad_pcb]
2023-03-03 add JLCPCB assembly files
    [BOM-TerasicDECACape.csv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]
2023-04-14 first version of the Pmod
    [MiSTeX-Pmod.kicad_pcb, MiSTeX-Pmod.kicad_sch, MiSTeX-Pmod.sch]
2023-04-14 change USB host connector, old one was out of stock
    [MiSTeX-Pmod.kicad_pcb, MiSTeX-Pmod.kicad_sch]
2023-04-14 add production files
    [MiSTeX-Pmod-CuBottom.gbr, MiSTeX-Pmod-CuIn1.gbr, MiSTeX-Pmod-CuIn2.gbr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]
2023-04-18 update schematic title
    [MiSTeX-Pmod.kicad_sch]
2023-05-15 MiSTeX Pmod: fix USB emc protection diode stubs
    [MiSTeX-Pmod-CuBottom.gbr, MiSTeX-Pmod-CuIn1.gbr, MiSTeX-Pmod-CuIn2.gbr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]
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2024-01-19 First WIP version of QMTech-MiSTeX baseboard
    [HDMI.kicad_sch, QMTech-MiSTeX.kicad_pcb, QMTech-MiSTeX.kicad_sch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]
2024-01-19 show the schematic borders and fix the design to fit
    [HDMI.kicad_sch, QMTech-MiSTeX.kicad_sch, VGA.kicad_sch]
2024-01-19 put the MiSTeX mascot on the schematic pages
    [HDMI.kicad_sch, QMTech-MiSTeX.kicad_sch, ResistorDAC.kicad_sch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]
2024-01-19 move SNAC into its own sheet
    [QMTech-MiSTeX.kicad_sch, SNAC.kicad_sch]
2024-01-20 fix SNAC pinout to match with the mapping described in sys/mt32pi.v
    [SNAC.kicad_sch]
2024-01-20 apply review notes from somhi, move audio into its own subsheet, add analog audio out
    [Audio.kicad_sch, HDMI.kicad_sch, QMTech-MiSTeX.kicad_sch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]
2024-01-20 add I2C to FPGA pins
    [QMTech-MiSTeX.kicad_sch]
2024-01-21 add UART connections
    [Audio.kicad_sch, QMTech-MiSTeX.kicad_sch, Schematic-RP2040.kicad_sch]
2024-01-22 QMTech-MiSTeX: make I2S audio to the DVI optional, use SPDIF by default
    [Audio.kicad_sch, HDMI.kicad_sch]
2024-01-23 finish routing/layouting, fix silk screen, add mounting holes
    [Audio.kicad_sch, HDMI.kicad_sch, QMTech-MiSTeX.kicad_sch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]
2024-01-23 remove no unused SNAC schematic (has been combined with UserInterface)
    [SNAC.kicad_sch]
2024-01-23 fix DRC errors and some warnings too
    [Audio.kicad_sch, HDMI.kicad_sch, QMTech-MiSTeX.kicad_sch]
2024-01-23 get rid of SNAC mode switch and add OSD button instead
    [QMTech-MiSTeX.kicad_sch, UserInterface.kicad_sch]
2024-01-23 move RP2040 to the top of the PCB, because it was on the wrong side of the core board
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2024-01-23 swap locations of power port and micro sd
2024-01-23 fix power port label
2024-01-23 add a power switch and break out and break out 4 more GPIOs on RP2040
    [QMTech-MiSTeX.kicad_sch, Schematic-RP2040.kicad_sch]
2024-01-23 add test points for VGA signals
    [VGA.kicad_sch]
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2024-01-23 fix rp2040 usb running over a power plane split
2024-01-24 tidy schematic and exclude pin headers from BoM
    [QMTech-MiSTeX.kicad_sch]
2024-02-05 QMTech-MiSTeX: OSHW logo on front mask, add instructions for installing SDRAM
    [QMTech-MiSTeX.kicad_sch, UserInterface.kicad_sch]
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2024-02-08 power filtering, testpoints, bottom caps, more decoupling, teardrops
    [Audio.kicad_sch, HDMI.kicad_sch, QMTech-MiSTeX.kicad_sch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]
2024-02-08 remove power switch because of bad quality, add BOM/CPL
    [BOM-QMTech-MiSTeX.csv, QMTech-MiSTeX.kicad_sch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]
2024-02-08 MiSTeX-Pmod: add missing assembly files
    [BOM-MiSTeX-Pmod.csv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]
2024-02-08 remove raw gerber files. we already have the .zip
    [QMTech-MiSTeX-CuBottom.gbr, QMTech-MiSTeX-CuIn1.gbr, QMTech-MiSTeX-CuIn2.gbr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]
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2024-02-09 QMTech-MiSTeX: fix swapped DQ14/15 pins
    [QMTech-MiSTeX.kicad_sch]
2024-02-11 connect buttons to the HPS, not the FPGA, because the FPGA does not use them
    [QMTech-MiSTeX.kicad_sch, UserInterface.kicad_sch]
2024-02-14 use stricter design rules and cleanup all DRC errors
    [QMTech-MiSTeX.kicad_sch, UserInterface.kicad_sch]
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2024-02-15 connect two remaining pins to new 2 row Pmod, fix via, tidy test points
    [Audio.kicad_sch, QMTech-MiSTeX.kicad_sch, UserInterface.kicad_sch]
2024-02-15 don't include DNP parts in BOM
    [QMTech-MiSTeX.kicad_sch]
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2024-02-15 add front switch, reroute USB, test points
    [QMTech-MiSTeX.kicad_sch, UserInterface.kicad_sch]
2024-02-16 Add VGA green probe, add DIP switches, add to silk screen, cosmetics
    [QMTech-MiSTeX.kicad_sch, UserInterface.kicad_sch, VGA.kicad_sch]
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2024-02-16 Add ESD protection to headphone jack and Pmod
    [QMTech-MiSTeX.kicad_sch, UserInterface.kicad_sch]
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2024-02-17 add CC1 and CC2 resistors to power connector
    [QMTech-MiSTeX.kicad_sch]
2024-02-19 add pin headers for buttons, add LED to RP2040, break out ADCs
    [Schematic-RP2040.kicad_sch, UserInterface.kicad_sch]
2024-02-19 Use yellow LED for RP2040, because green is out of stock
    [Schematic-RP2040.kicad_sch]
2024-02-20 Add power switch header
    [QMTech-MiSTeX.kicad_sch]
2024-02-21 add ground pin near USB test points, add GND vias to rp2040 center pad
    [UserInterface.kicad_sch]
2024-02-22 Order for rev1 is out to the fab
    [BOM-QMTech-MiSTeX.csv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]
2024-02-24 add headers for LEDs
    [UserInterface.kicad_sch]
2024-03-07 fix side switches, vias under uFL connectors, silk screen
    [QMTech-MiSTeX.kicad_sch, UserInterface.kicad_sch]
2024-03-25 update to KiCAD 8 and regenerate production files, with latching switches
    [BOM-QMTech-MiSTeX.csv, HDMI.kicad_sch, QMTech-MiSTeX.kicad_sch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]
2024-03-25 fix SW5,SW6, make them latching
    [BOM-QMTech-MiSTeX.csv]
2024-03-25 fix silkscreen names, sizes and positions after update pcb mess
2024-03-25 kicad 8 fixes (3d model paths)
2024-03-26 add rp2040 vbus, bump rev date, add USB_BOOT connection to RPi
    [BOM-QMTech-MiSTeX.csv, QMTech-MiSTeX.kicad_sch, Schematic-RP2040.kicad_sch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]
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2024-04-02 add MiSTeX Kun big logo, swap ferrite bead with in-stock part
    [BOM-QMTech-MiSTeX.csv, QMTech-MiSTeX.kicad_sch]
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
